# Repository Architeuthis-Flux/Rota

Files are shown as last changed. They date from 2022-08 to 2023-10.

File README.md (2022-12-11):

# Rǒta
Here are some different Rǒtas with different options


IMG_0975b copttty



1_0_GIF_2 4

That flashing means it wants your input. These decimal points do way more work than regular decimal points, they tell you a lot about what's going on. When you don't have segments to make crude letters and stuff, you need to get creative with dots.

https://user-images.githubusercontent.com/20519442/197625332-2014cbfb-5107-4166-b01f-a8d20bc4a214.mp4



Rǒta is a tool for counting things while being all nerdily extra about it. Are there more efficient ways to count things? Yes. But will those things increase your exposure to Nixie tubes and rotary dials? No? Well then if that's what passes for progress nowadays then I'm going to go live on a mountain somewhere and count things the cooler way, with nixie tubes.

IMG_0975b

It was originally conceived as a gift for a duck hunting lodge, but now I'm making a few more and I know not everyone is into hunting so it's been generalized into a tool for just counting stuff in general where those $3 hand clickers or a golf pencil just lacks the glamour you need in your life. 

Instead of using sequences of numbers to use the special functions, now you just dial 0 and then the function you want which is printed on the number plate. 

here's the special function menu map
```
note - I'm calling moving the dial just a little to turn the display on a "click"
when inside a special function, dial anything to exit (preferably 0 because it's only reading intermittently when in menus, so it's most likely to register)

0 -- enter/exit menu or function   shows 111 when you're in the menu)
1 -- stopwatch                    click to start, click again to see last time.
2 -- show battery voltage         briefly turns off the display to get a more accurate reading (not under load)
3 -- new day                      this stores the total since the last time you started a new day. maximum 63 days
4 -- does nothing
5 -- enter a count by digits      enter 3 digits (hundreds - tens - ones) to add to your daily total
6 -- show history                 click through each day with first the day number (on the left) then the total for that day
7 -- toggle day/total display     either shows the count for that day or the running total of all days (default is total)
8 -- golf mode                    keep score for golf - first enter 1-4 players and the decimal points show which player's turn it is
9 -- clear everything             dial 9 again to confirm. dial anything else to go back
999999 -- emergency clear         dial 9 six times to emergency clear everything in case something gets messed up same as dialing 10 9 9
                                  you can also short the middle pulse pin high for super duper emergency clear

```

The voltage display was added because I was having issues with the K155ID1s browning out before the HV module (it still blows my mind that it works down to like 3V), so the display would just show all the digits on because the nixie drivers weren't blocking any current. 

So now I added a HV shutdown and a super simple voltage sense divider that drops the 9 down by half so it can be read by the AVR64DD32's ADC.

Now if the battery voltage is too low, it shuts down the display but still takes input. In case you don't have a spare battery but still want to count. And the power draw is so low for just the microcontroller that the battery life might as well be infinite.

https://user-images.githubusercontent.com/20519442/197626419-59003e0c-a97b-495f-a466-c8ea541df162.mp4

If you notice in the video, the display flashes when the battery voltage updates, that's because when it does the measurement, it briefly shuts the HV module down so we can measure the battery voltage unloaded. Because this thing draws ~300-400mA when it's on so without doing a ton of math and testing different 9v batteries to correct for it, the voltage it shows would be like ~2V lower than it really is unloaded. 

I probably should have put in a fresher battery before I filmed this. 

I also had to design a case for this because I'd always get anxious watching other people use it without one. People with smaller hands tend to put their fingers right on the high voltage section on the back of the Nixies. 


This project really helped me change my lukewarm feelings towards rapid prototyping, I've had a 3D printer for years but never really used it much. I found out the reason it never worked is the original spool of filament Sindoh included was garbage. So my prints would always turn into an absolute mess of spaghetti. I finally bought a fresh spool of filament and it works great now.



I'll definitely have the case made by someone with a more expensive printer when I sell these or give them away, but to get the fit right and make sure there's room for everything inside, 3D printing really saved the day here.

RotaNumberPlate

Putting in the number plate (which I just found out the name of) on these old dials really makes you appreciate how much thought they put into things in the 60's. Like on most phones you would only do this once, but they came up with a really cool system for it.

How you do it is by sticking a screwdriver under the ring at the 6 and moving a lever down to the 8 position to release the middle thing.




With it off you can see what's going on 



Then you just twist this pressure plate and it comes off. 



This isn't the final number plate from above because I'm a millennial and don't have a regular 2D printer. But I might try it on a plotter or a silkscreen to get a nicer finish.

I had to move the holes a bit to get it to line up with the dial, I must have carelessly moved the holes on the Edge Cuts layer in Kicad, but the new Kicad files on here are fixed (as well as a couple other problems) if you want to have these boards made yourself. 



Yes I cleaned that flux off. For Nixies it's particularly important because flux lets enough current flow at that voltage to cause ghosting. I had a lot of problems wit ghosting on the first digit and I tried a bunch of things to get rid of it, eventually what fixed it for me was putting a 220KΩ resistor between high voltage and ground to both drop the voltage a bit (these tiny HV modules don't have an adjustment knob like the bigger ones) and bleed off the extra charge you get when you do low-side switching on nixies.



PCBway was nice enough to sponsor this project. I had never used them before but the boards they sent were great. And their matte black finish is really velvety. 

It really seems like they spend a good deal of time with a human looking at your boards and making sure there aren't any problems. And I usually do a lot of weird stuff with my boards that falls outside of the usual best practices of PCB design. But they seemed to roll with it pretty well and make sure I did it on purpose (that came up a lot more with breadWare which they also sponsored.) Which is crazy to me because of how cheap the service is. You'd think it wouldn't be worth their time for my ~$20. 

Either way, I was ready to just pay them for my boards if they were shitty and say so here. But that wasn't necessary because they really did a great job on these. 

# RotaDuck (this is the previous revision so I'm leaving this here)
Sticking Nixie tubes to an old rotary telephone dial

Here's a video of it in action

https://user-images.githubusercontent.com/20519442/176002505-34b7ac66-cf38-471d-8984-42ffa85f04d7.mp4

And there's a few more on my [Youtube channel](https://www.youtube.com/user/arabidsquid/videos)



I'll do a more complete write-up at some point in the future, but for now I'll mention a few things.

It stores the running count (and a history of recent entries) in EEPROM because when the dial returns to it's resting position, the power is completely cut off. That makes it so I couldn't just use timing to figure out when the pulses stop (and the number that was ultimately dialed) so instead I put in a resistor ladder so the between the 3 contacts on the dial to give me 1/2 voltage on the last number, when the dial is between 0 and the end. that gives me a waveform like this:
```
   _   _   _   _
__| |_| |_| |_| |_,-,___
```
So it does all the saving during that shorter last pulse, which is pretty tight because EEPROM access is relatively slow. 



I didn't want to add any buttons to it so instead it uses multiple 9s and 0s for special codes, here's the list of what they do
```
0   - subtract the next number dialed from the total
000 - clear all counts to 0

9   - show total for all days
99  - list each day and the total for each
999 - start a new day
```
Here's what I'm talking about when I say days. So this was originally designed for duck hunting (hence the duck in the name) as a gift for a duck hunting club. If you want to count how many ducks you got, we'd usually bring one of those mechanical clicker counters and just keep a running total.But I figured if I'm making a thing to count how many ducks were shot during a trip, it might also be useful to have that information separated by days if you want to keep a separate daily and running total. 

At some point I'll print that menu in the middle of the dial.



If you intend to make one of these for yourself, you should probably know this thing is like 90% bodges and perfboard circuits. I eyeballed the shape of the dial cutout nearly perfect, except that it's flipped on the board. So instead of just redoing the board like a sane person, I just mounted it with everything on the wrong side and bodged wired a ton of things to make it work. That's why there are those arrays in the code to convert the number shown to the number its actually wired to. So if you really want one, let me know and I can do a version 2 that will be 100x easier to put together. 




I also made a rechargeable one by dead bug soldering a tiny 10DFN MCP73213T charge controller and putting in 2 1/2 AA sized lithium batteries, but after using it a while, the simplicity of just using a 9 volt battery is much nicer (and lasts a lot longer.)


Eventually that red wire sticking out will be connected to a barrel jack port. Once I decide on an enclosure.


oshw_facts (1)

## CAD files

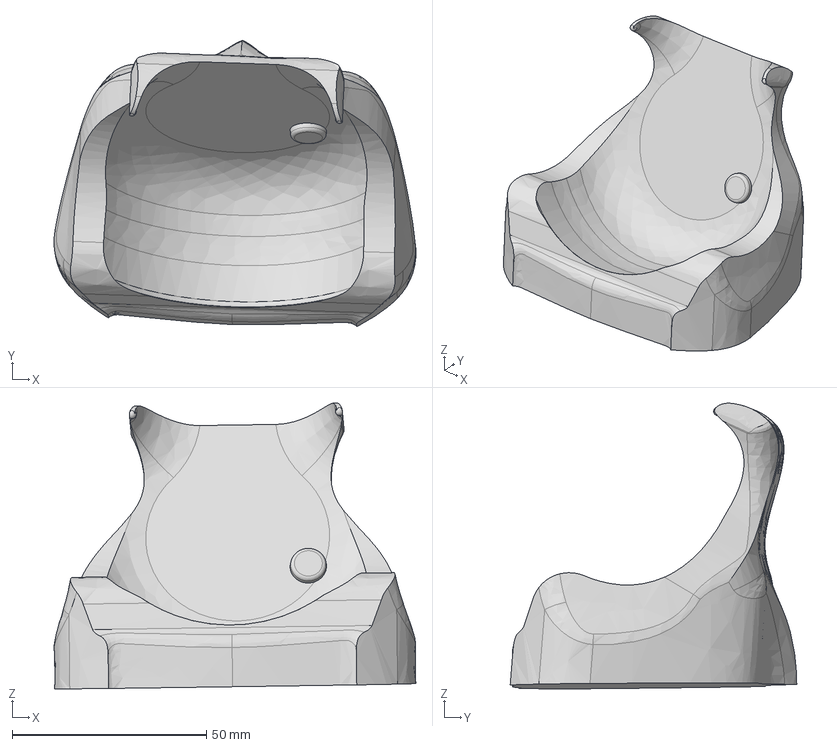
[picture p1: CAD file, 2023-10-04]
Case 3D Models/stand2lean v2.step
93.3 x 73.8 x 73.6 mm

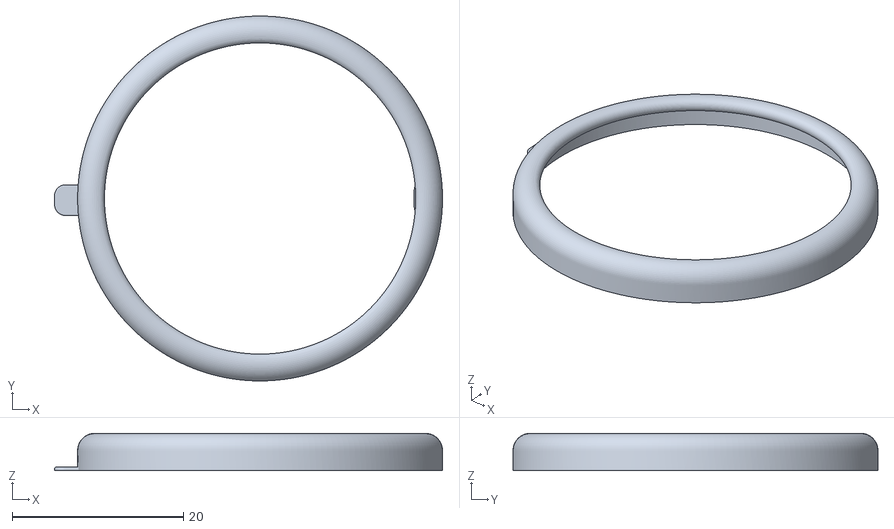
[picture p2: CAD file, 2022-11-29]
Case 3D Models/centerset4 copy.stl
45.3 x 42.6 x 4.36

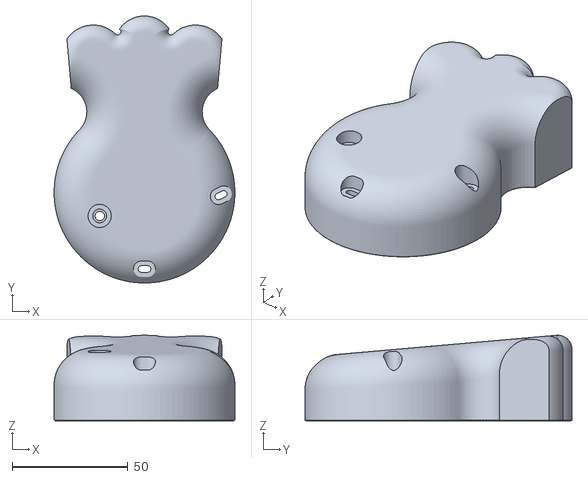
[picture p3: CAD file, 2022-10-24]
Case 3D Models/Bodyds9.stl
78.0 x 115.1 x 36.9

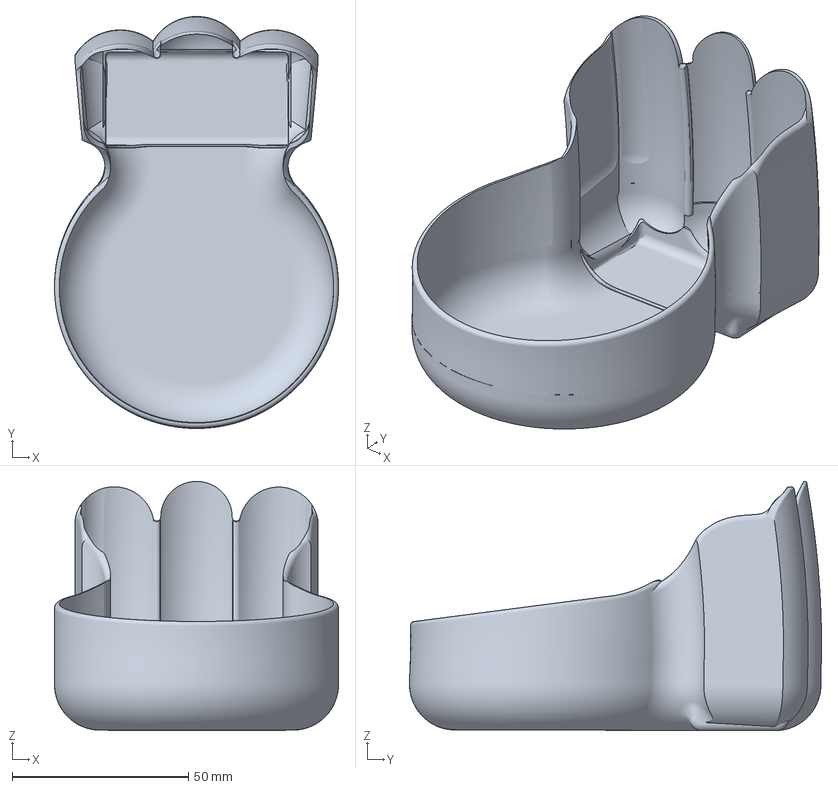
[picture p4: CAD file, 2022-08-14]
Case 3D Models/Rota7.3mf
80.5 x 116.8 x 70.6 mm

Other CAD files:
Case 3D Models/stand2lean v2.stl

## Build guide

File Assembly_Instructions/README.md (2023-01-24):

# Rǒta Assembly Instructions

Congrats on your new Rota! Now let's put this thing together.

## Here's what you should have in your kit
Assuming you got the full kit, you should have:

* 1 Rota PCB with assembled SMD parts
    * (If I gave you one with a warning about there being some issues that need to be fixed, [here's the guide to fix them](RotaErrata.jpg))
* 3 [IN-12B](http://www.tube-tester.com/sites/nixie/dat_arch/IN-12A_IN-12B_03.pdf) Nixie Tubes
* 3 [K155ID1](https://tubehobby.com/datasheets/k155id1.pdf) Nixie BCD drive ICs
* 1 [IN-3](https://tubehobby.com/datasheets/in3.pdf) Neon indicator bulb
* 1 [NCH82000HV](https://omnixie.com/products/nch8200hv-nixie-hv-power-module) High Voltage DC-DC converter module
* A Bag containing:
    * 2 printed number plate cards
        * If you ordered a plastic dial, I've also thrown in a slightly smaller number plate card that might look better with them, but you can use either one.
    * 2 plastic number plate covers
    * Some extra plastic spacers for the dial contactors
* Another bag containing:
    * 7 ~2" bits of wire
    * 6 Terminal lugs
    * 2 1x3 Male header pins
    * Some short bits of heat shrink tubing
    * 1 9V battery connector
* 1 Dial insulator
* 1 3D printed case

## Here's what you'll need that isn't included

* Soldering iron
* Solder
* Small-ish flathead screwdriver
* Flush Cut wire cutters
* Small needle-nose pliers
* Something to remove flux (isopropyl alcohol or flux remover or whatever)
* A multimeter (optional, sort of)
* An Xacto blade
* You might need some 1" screws that thread into your dial to attach the case
    * The threads these dials come with have an old thread pitch that's hard to find machine screws for, if you ordered the dial from me, I've recut the threads to fit 4-40 machine screws. They're close enough in pitch and the metal these dials are cast from is soft enough that if you really want to, you could probably just force a 4-40 screw in there and cut new threads that way. 

## Step 0 (checking my work)
The AVR64DD28 microcontrollers were soldered on by hand without the use of a solder paste stencil (the rest of the parts are already populated by JLCPCB so it wouldn't lay flat enough to be helpful), I check each one for shorts an unconnected pins but it's always possible that I missed something. So it might be helpful if you're the meticulous type to put your multimeter in continuity mode and make sure adjacent pins arent shorted. If you find one, I usually just use an Xacto knife blade side up and sort of floss between the pins to cut any tiny solder bridges. 

Or you can trust my work until the end and only do this if there's a problem. 

# Step 1 - Nixie Driver ICs

First, stick in the ICs so the notch aligns with the one silkscreened on the board. 
You'll probably need to bend the pins in a bit to get them to line up with the slightly smaller than usual through holes. 
ics 

A thing to remember here is that this board will be laid flat against the dial, so it's important to keep everything on the back side super flush with the board.
I find that pushing them in really snug into the holes, cutting all the pins flush, then letting them come back out a fraction on a millimeter before soldering gives really flat solder joints. 
ics 
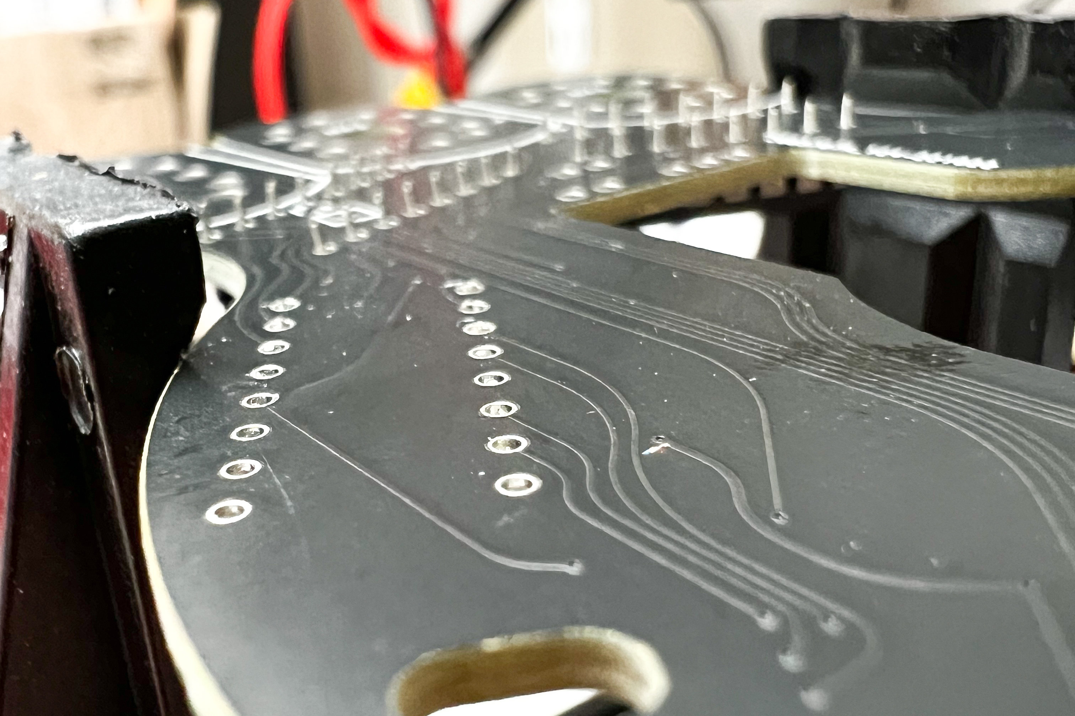
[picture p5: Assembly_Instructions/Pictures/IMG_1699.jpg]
 
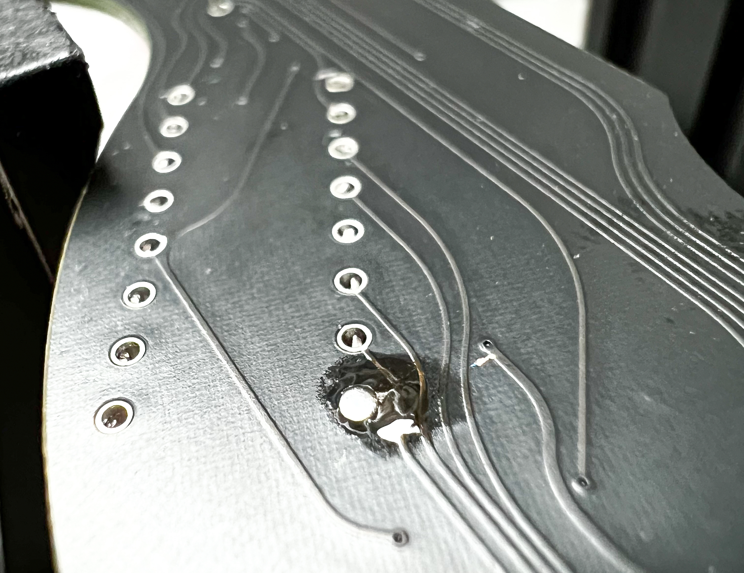
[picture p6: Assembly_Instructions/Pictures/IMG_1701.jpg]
 

# Step 2 - Dial Lugs / Battery Holder
Now we need to make the dial lugs that will connect the board to the dial. 

First, grab one of the lugs with your pliers on only one side of the split
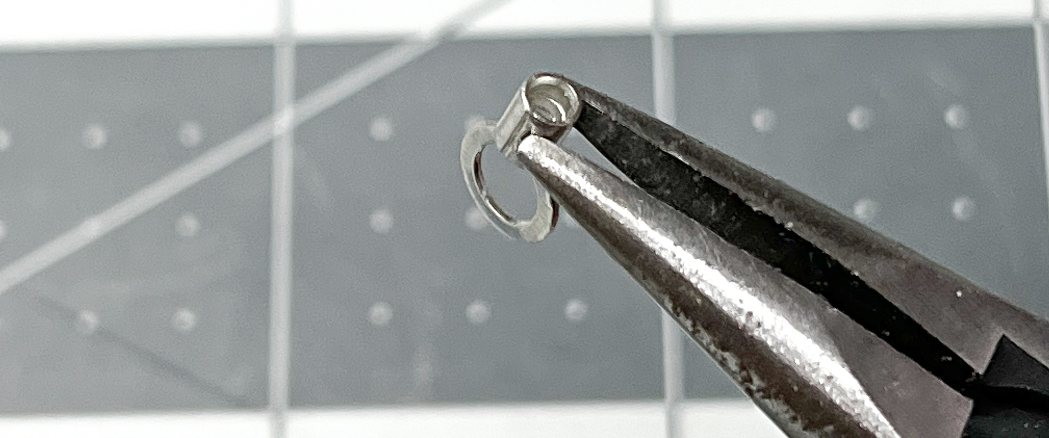
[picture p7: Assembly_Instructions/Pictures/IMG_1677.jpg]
 
and squish it most of the way down (leave enough room for the wire.)
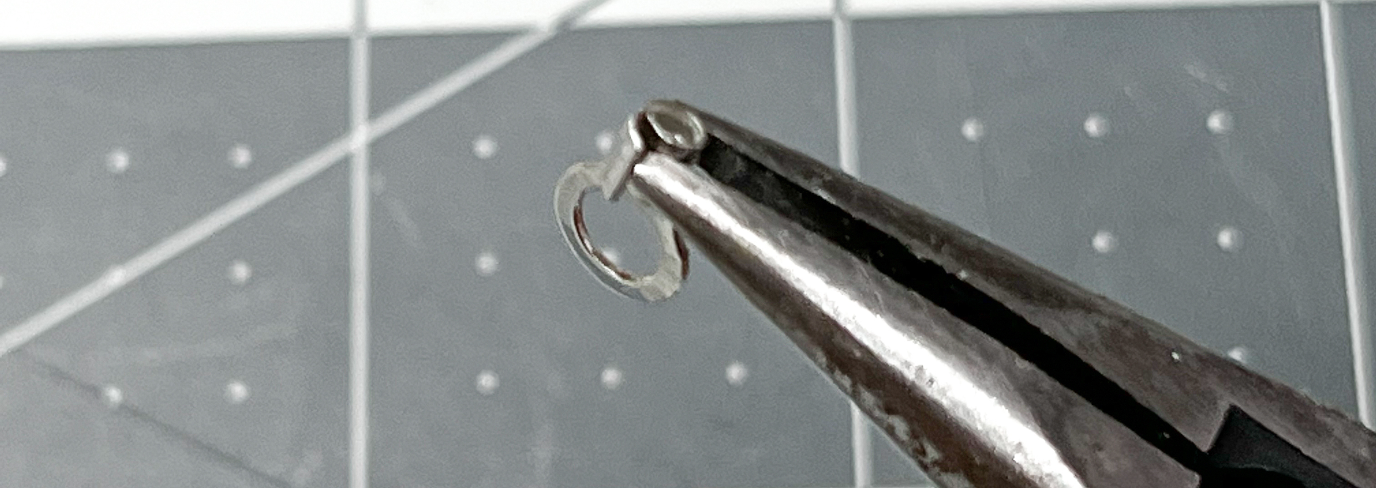
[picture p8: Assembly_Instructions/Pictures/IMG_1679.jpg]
 
Now strip off like 1/4" of one end of a wire and stick it in
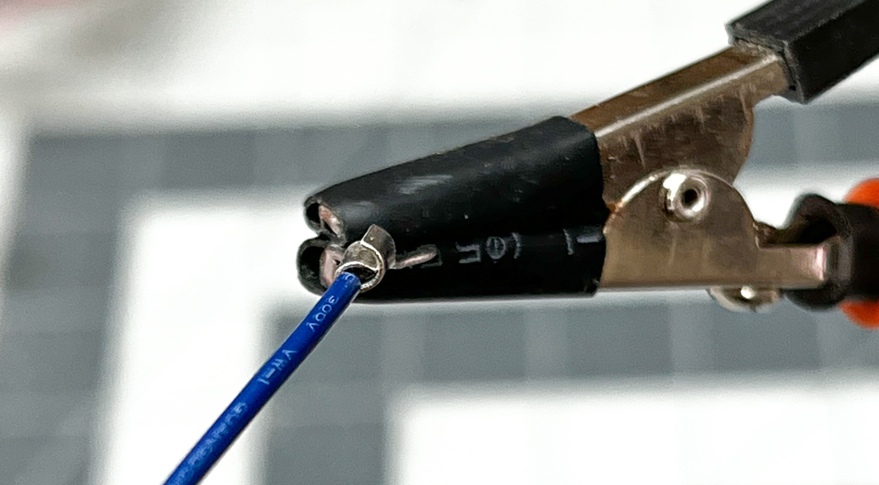
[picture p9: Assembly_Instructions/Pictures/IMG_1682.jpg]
 
Squish down the other flap so it holds the wire snugly, you might want to press the sides in a bit so it's not so wide and flat.
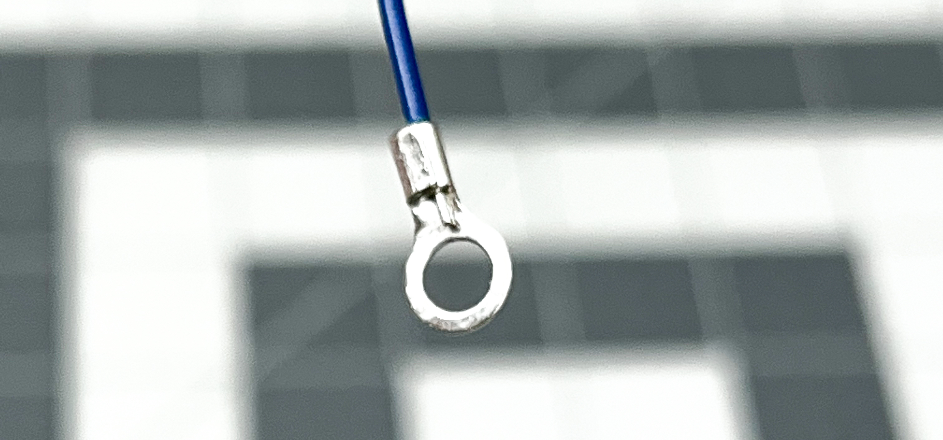
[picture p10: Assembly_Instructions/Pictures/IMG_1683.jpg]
 
Add some solder
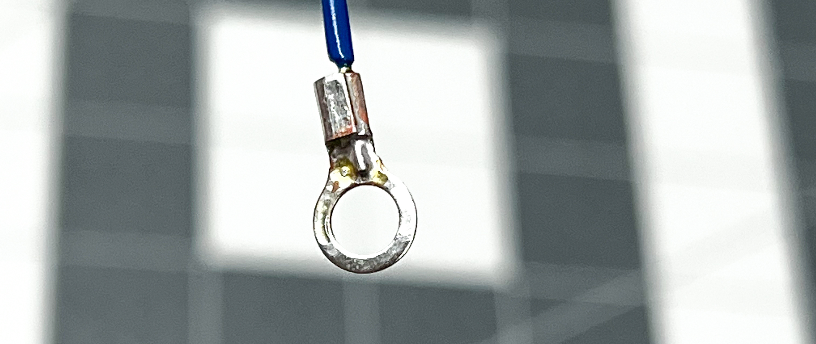
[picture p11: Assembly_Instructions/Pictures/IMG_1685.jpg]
 
and heat shrink it
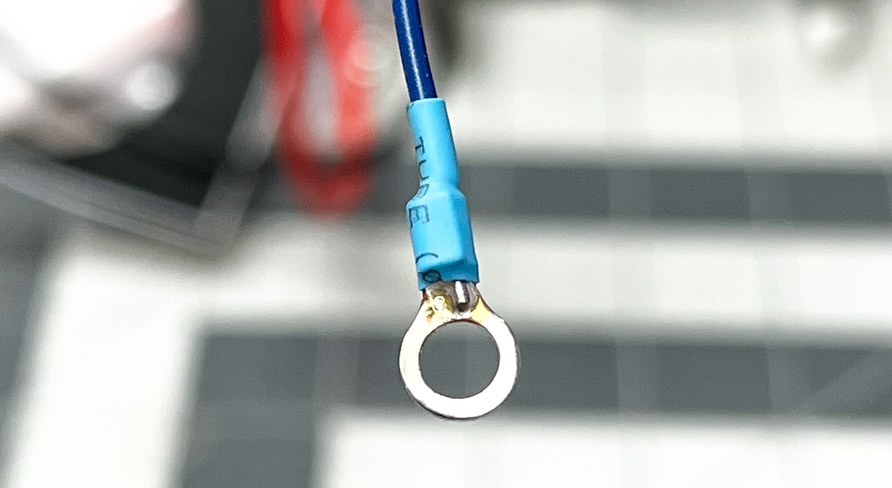
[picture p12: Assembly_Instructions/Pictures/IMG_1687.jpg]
 

Now repeat this process 4 more times until you have 5 soldered up lugs/wires. (Most kits have the forked style seen at the far left here, these were just extras I had laying around)

lugs 

Cut and strip them so theyre about 1 1/4" long, and stick them in the 5 holes.

To get them to stay while you solder them, I bend them back and tape them down like this
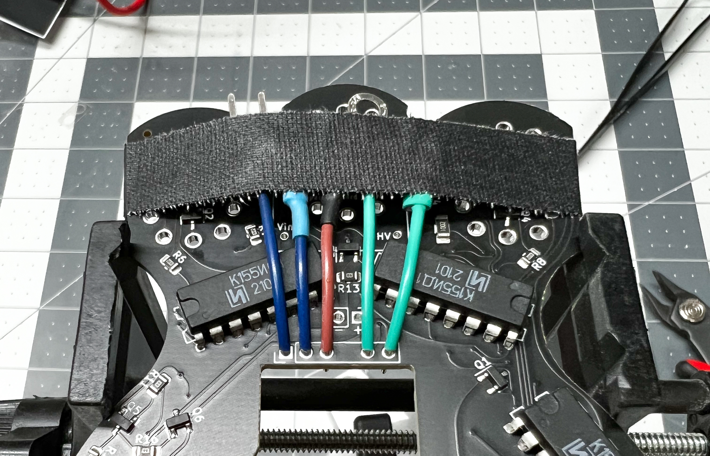
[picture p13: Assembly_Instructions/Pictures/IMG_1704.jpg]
 

We still want to keep the back of the board super flush so cut the parts sticking out and then solder them. 

With the battery holder, cut and strip the wires down to about 2 1/2" and solder them in (Red to + , black to -, obviously)

If your board has 6 holes (There's only 1-2 floating around in the wild,) just dont put anything in the 4th hole from the left.

# Step 3 - Nixie Tubes
This part I find is worth being a little picky about looks, you have 3 nixie tube that are matched for overall look as best I can, but once you start paying close attention to each one, you notice that there's a lot of variation from tube to tube. So it's a good idea to put shuffle the order of the tubes until you find an order that looks the most even to you. 

Most of them are a bit off-center in some direction, so part of the matching I do is to make sure if there's one that sort of goes to the left, there will be another that goes to the right. 

Once you have the order down, I set the whole thing face down with something supporting the bottom of the board so it all is flat

nix 
And then just solder the top pin of each tube. 
nix 

Now you can flip it over and melt the solder while adjusting the positions of the tubes so they're all evenly spaced and at the right angle and stuff. It's worth spending some time here getting it right because they're a huge pain to desolder once they're in.
nix 
(These are some *very* unmatched tubes, interestingly, the two on the left have the same date code)

Pro tip: use the outlines on the front of the board as a reference

Once you get it perfect, solder and cut all the pins (don't use your good cutters, these pins are hard and will ruin them)
nix 
Getting them super flat isn't important here.

Now make sure to clean the flux off *super duper extra* well here, like more than you'd usually deem necessary. At high voltages flux isn't a perfect insulator and the tiny current it passes is enough to cause other digits to partially come on that shouldn't be and it looks terrible. Like 90% of the troubleshooting I've done on these things ends up being flux related.

# Step 4 - HV Module
You'll notice that there's only 3 holes where the HV module connects to the board. That's because the two ground pins are connected and I needed to save space here. 

The board mounts with the parts facing toward the nixies to get some extra clearance for the 9V battery in the case. 

Find a 1x3 header and break it into individual pins (if you break the plastic part don't worry about it)

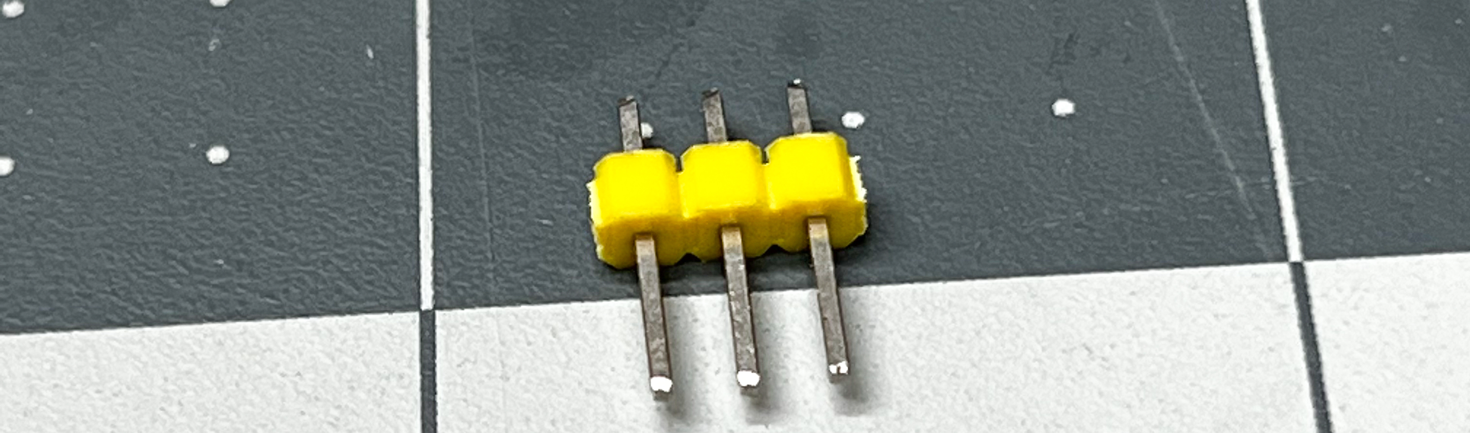
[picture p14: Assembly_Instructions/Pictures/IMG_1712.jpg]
 
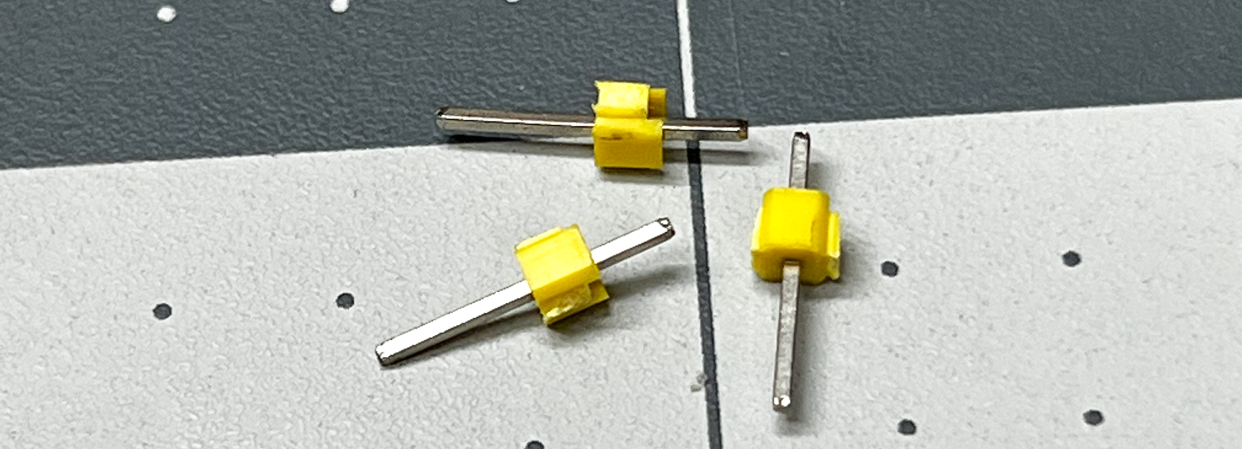
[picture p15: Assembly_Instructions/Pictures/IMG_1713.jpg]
 

The through holes on the Rota board are tight enough that they friction fit pretty well. Put the pins into the Rota board and then put the module on. 

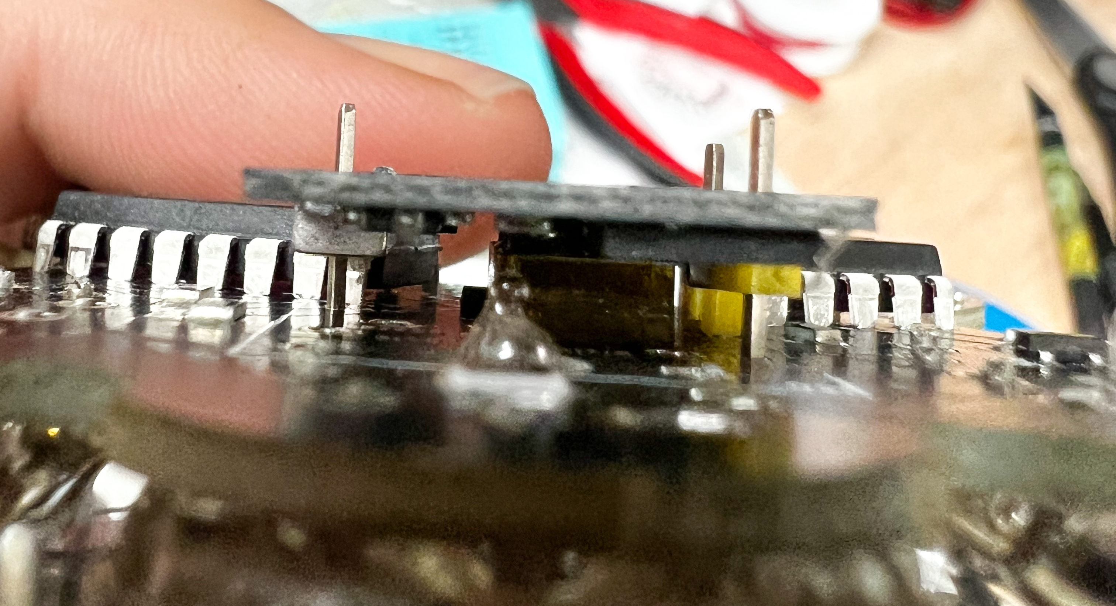
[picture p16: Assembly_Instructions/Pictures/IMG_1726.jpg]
 

You want to press the board down enough that the big square inductor on the board is as close as possible but not touching the Rota board. And that the evacuation nipple on the nixie tube isn't touching either. 

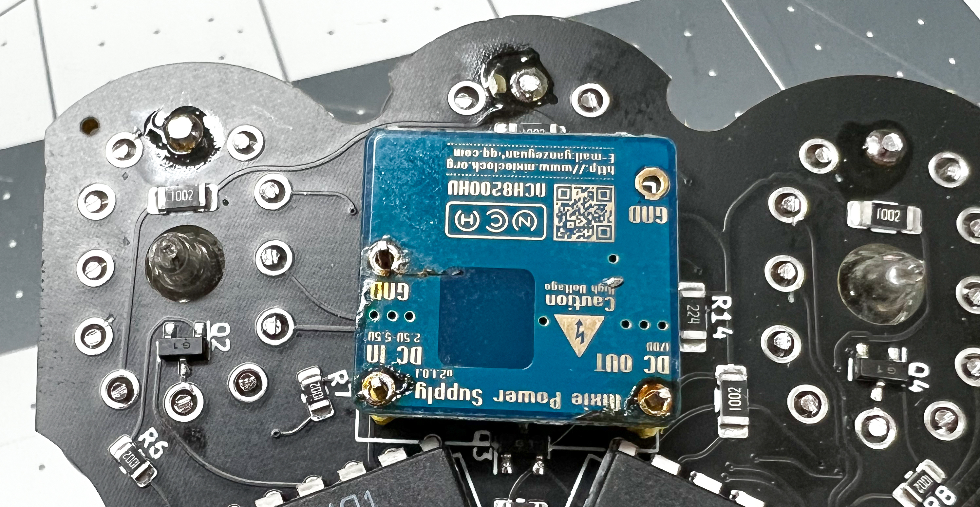
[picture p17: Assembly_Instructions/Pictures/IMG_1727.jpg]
 

Cut those pins super flush and then only solder the pins to the HV module. It stays in with friction so I usually wait until I know the board is working to solder it onto the Rota board.

# Step 5 - IN-3 Indicator
Use one of the small heat shrink tubes to measure out a height you want your IN-3 to sit at. 
in 
I usually prefer it 1/4" below the face of the nixie tubes. But it's up to you.
Now cut it and the other to that length and put them around the leads of the bulb and shrink it. 

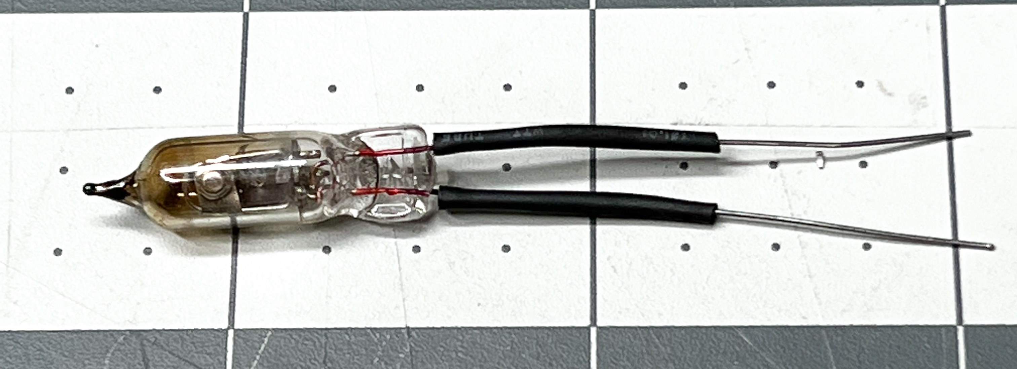
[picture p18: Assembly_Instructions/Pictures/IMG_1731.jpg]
 

Note that there are 2 sides to these bulbs, this is the side you want facing out
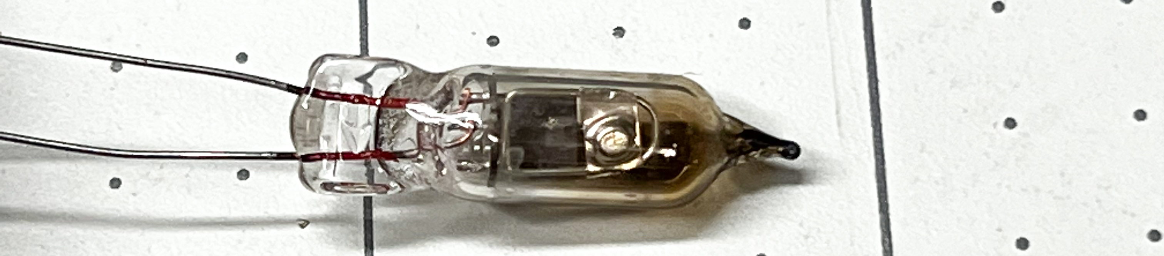
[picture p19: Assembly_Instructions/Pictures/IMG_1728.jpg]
 
This is the back side you want facing in towards the board.
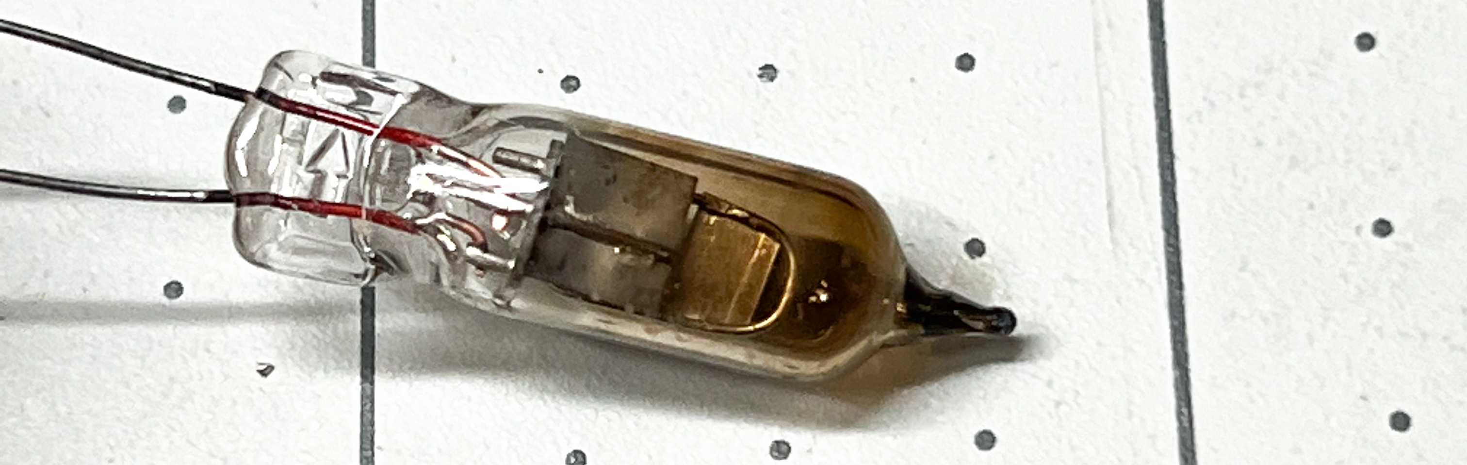
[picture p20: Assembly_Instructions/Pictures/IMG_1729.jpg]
 

(You can power these backwards and the glow comes off the wrong parts and looks kinda weird, feel free to try it if you want, it won't damage the bulb.)

Now cross the leads (because the footprint on the board is backwards) and cut the leads to a little over 1/8" 
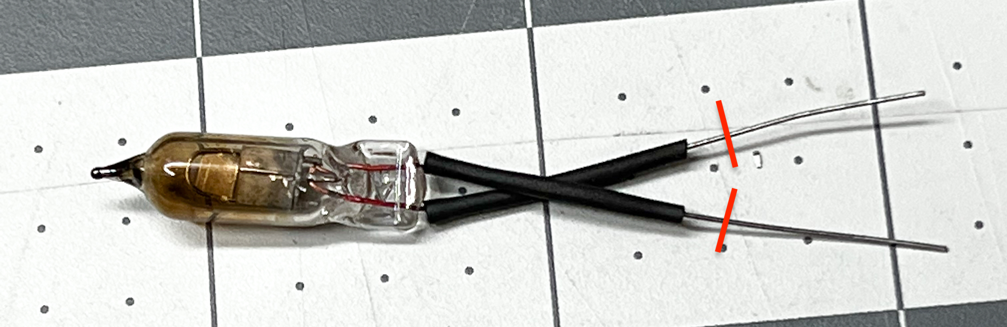
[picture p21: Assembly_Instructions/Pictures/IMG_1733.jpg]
 

Stick it in the board and solder it from the front. 

in 
in 

# Step 6 - The Dial

If you got a dial from me, this part should be done already. This is by far the trickiest part of this process. What we need to do is take a dial that originally comes like this 
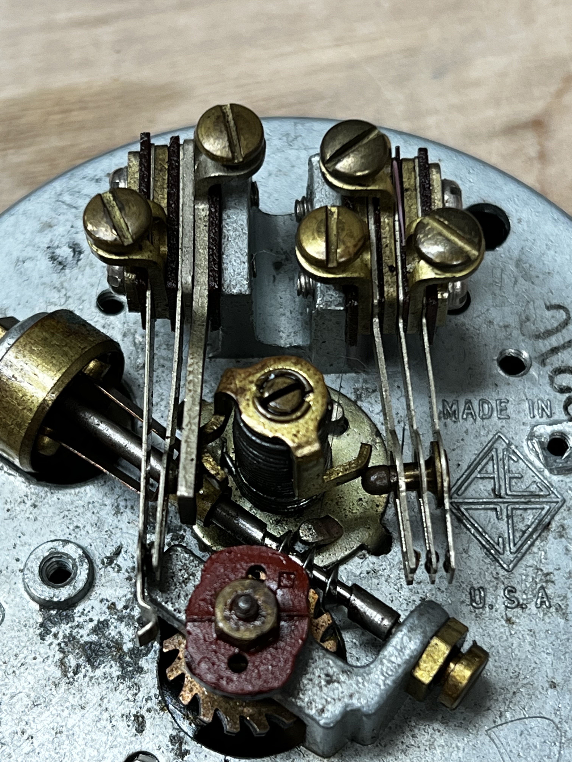
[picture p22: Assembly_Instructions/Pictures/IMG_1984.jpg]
 
And move one of those screw teminals from the right to the left side so it looks like this
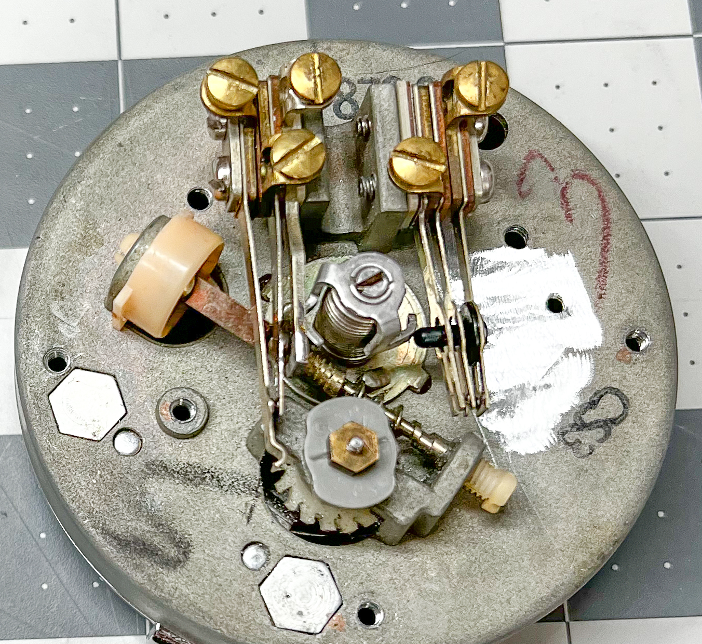
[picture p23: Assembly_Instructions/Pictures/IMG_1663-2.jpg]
 

## The Flattening
Depending on the dial you have, some will have a raised screw hole on the left side near where it says "Made In U.S.A." That needs to be sanded flat (shown in the picture above) or just use cutters and clip it off. It's cast zinc so it's surprisingly soft. 

Now the only thing sticking up should be the one on the left. 

## The Insulating

So the dial doesnt short any contacts when it's screwed tight againt the board, there's a piece of cut out gaffer's tape in the kit

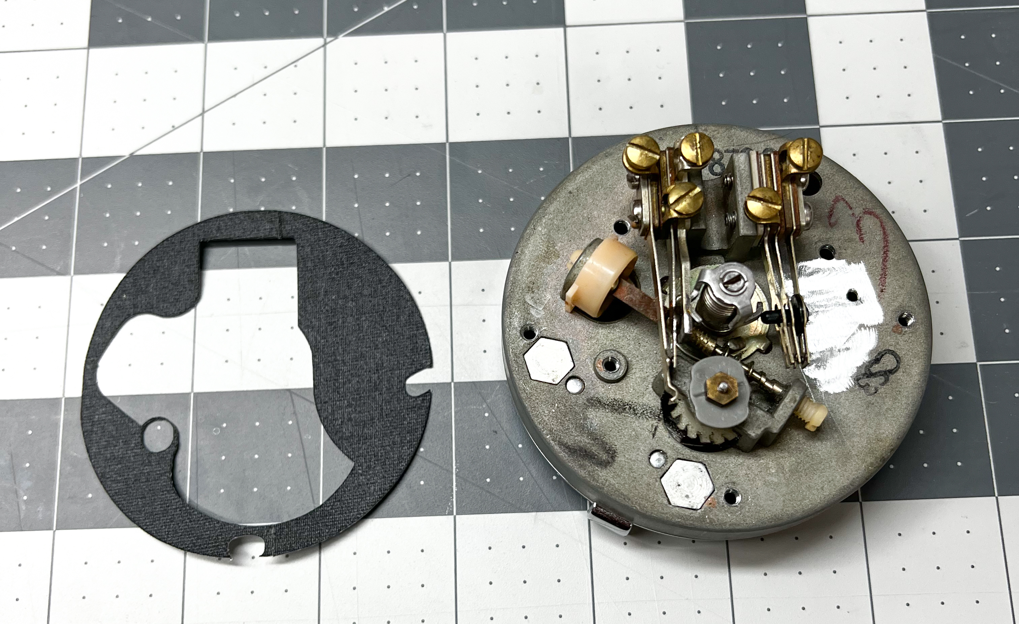
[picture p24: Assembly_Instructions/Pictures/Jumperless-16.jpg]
 

Use tweezers to peel each half off the backing and do your best to stick it on lined up with the holes (perfect alignment is not crucial)

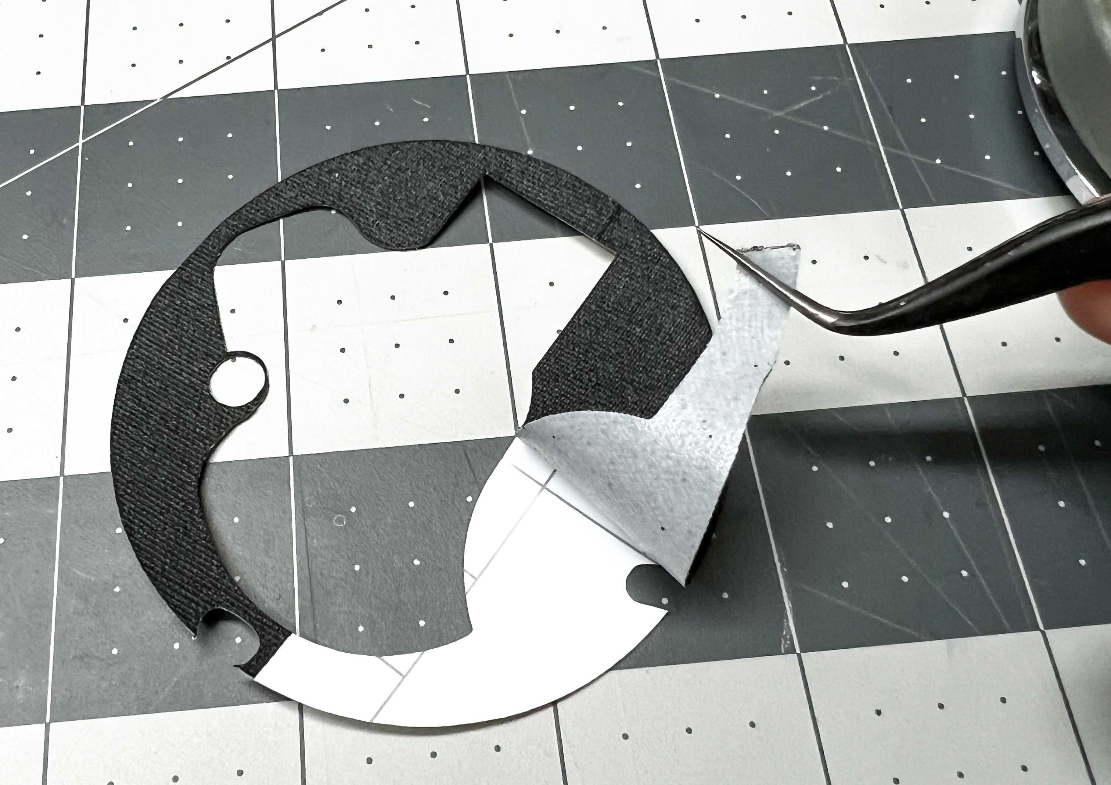
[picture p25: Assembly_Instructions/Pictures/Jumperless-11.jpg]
 
dial 
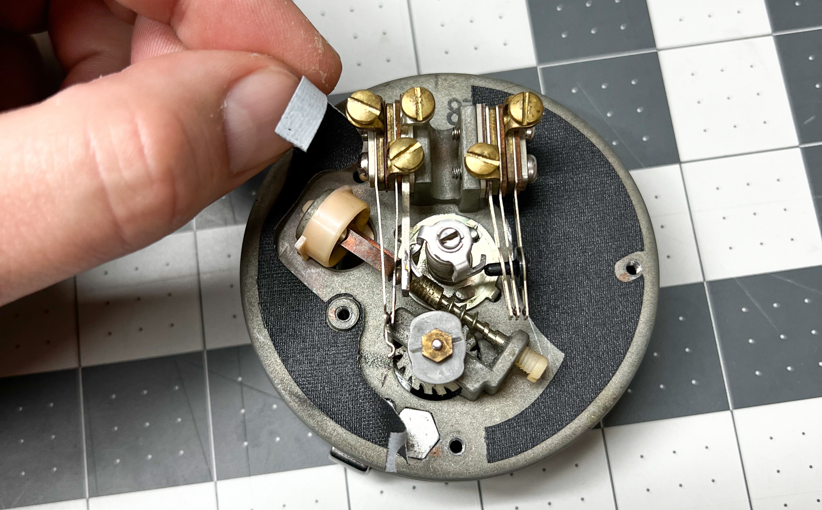
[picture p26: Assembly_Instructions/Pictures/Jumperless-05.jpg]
 
dial 

## The Fiddly Bit
I can't step-by step through this part because it's a bit different for each dial depending on age and wear and stuff. but here's the final goal

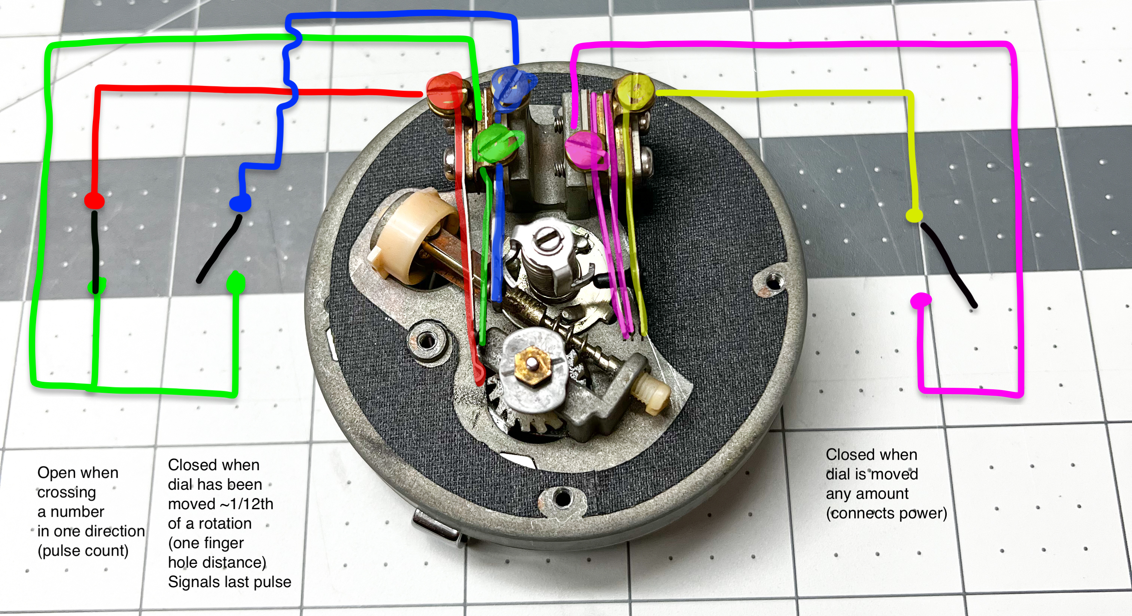
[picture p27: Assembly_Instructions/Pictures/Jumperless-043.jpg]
 

Here's what that looks like on an oscillocsope

The traces go from left to right, 

trace 1 is the pulse (left side, left contact, red above)

trace 2 is pulled to ground through a 10K resistor (left side, middle contact, green above), 

trace 3 is pulled high through a 100ohm resistor (left side, right contact, blue above)

trace 4 is continuity through the right side contacts

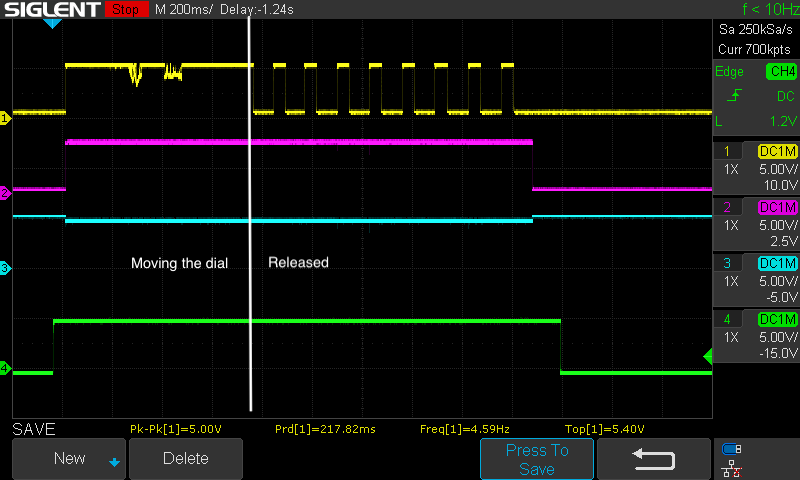
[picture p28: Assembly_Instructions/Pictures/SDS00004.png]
 

So unscrew the the screws holding the contactor arms

dial 

and lay them out in order 

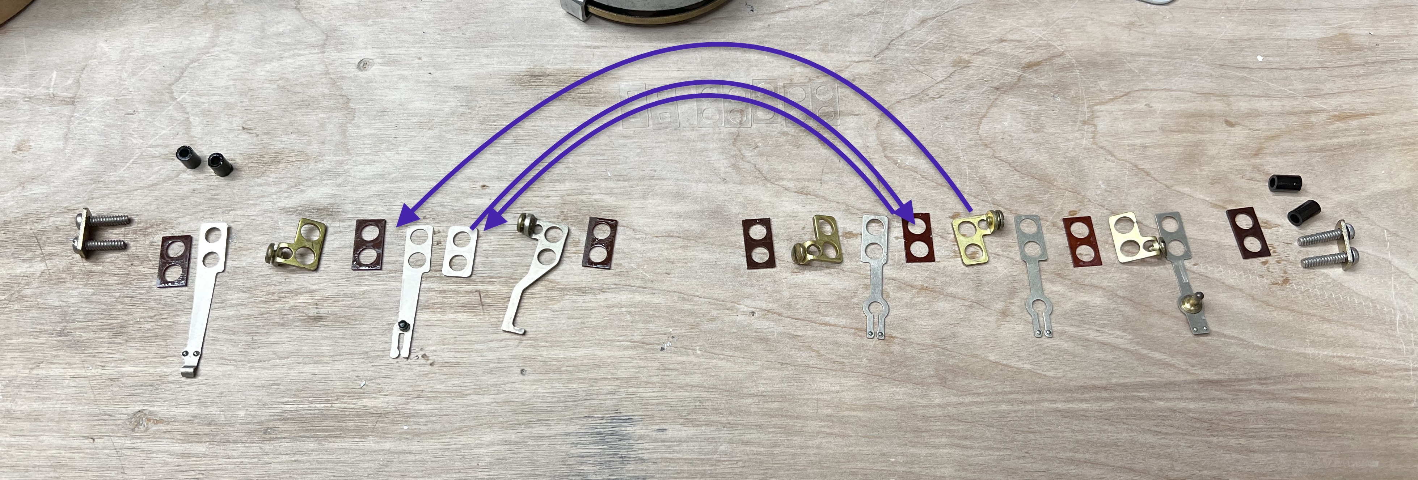
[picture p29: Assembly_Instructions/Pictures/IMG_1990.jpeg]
 

swap the parts marked with purple arrows and flip the metal pice with the screw terminal around so it faces away from the one next to it when you put them back on.

Make sure each of the contactors on the left side are isolated from one another.

Its helpful to cut those plastic spacers around the screws like a millimeter shorter and fillet the edges so they dont catch on the edges as easily.

Now put all the parts back on the screw and screw it all back on. Watch carefully to see if the contactors are making good contact when they should. 

They probably won't, you're going to need to add and remove spacers (and replace them with the thinner plastic ones I've provided) by trial and error until good contact gets made at the right times. You can bend the arms slightly as needed. Make sure everything's screwed in tight when you test them. 

This is an absolute pain in the ass. But don't give up, once it's set you wont have to do this again. 

Here are some examples of working stackups for reference (one has 2 extra arms on the right side but they're unused)

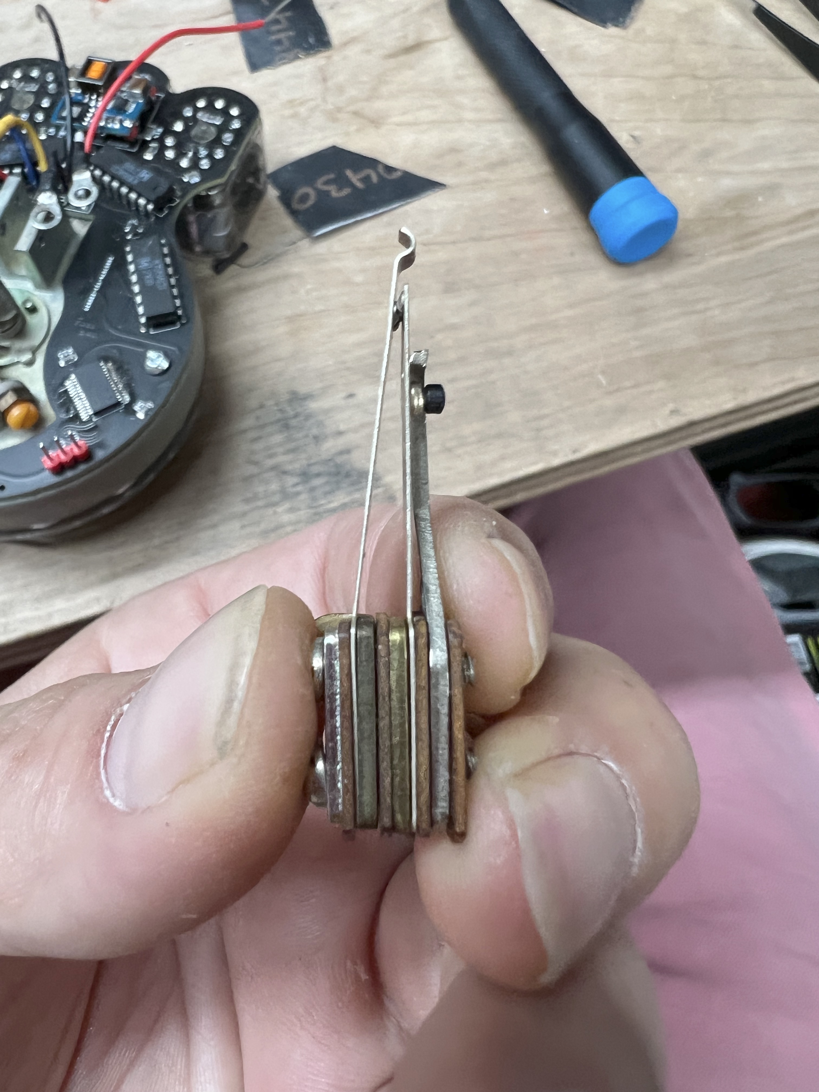
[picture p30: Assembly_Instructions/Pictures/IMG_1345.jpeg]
 
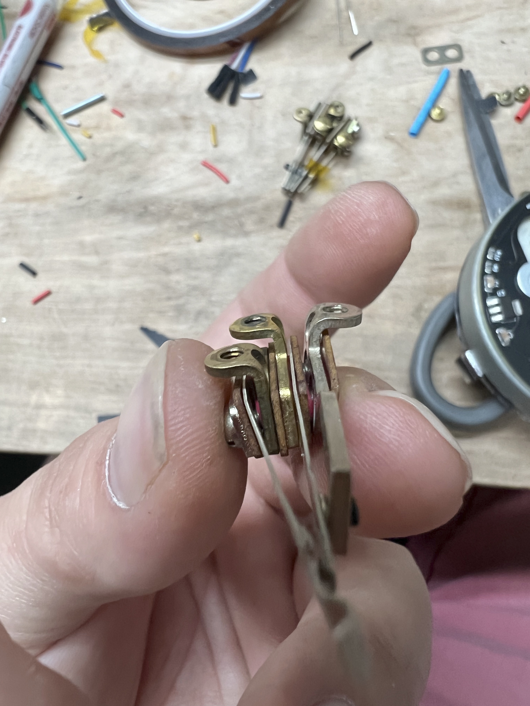
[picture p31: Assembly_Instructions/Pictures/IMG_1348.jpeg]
 
dial

At rest
dial 

Moving the dial
dial 

Mid pulse
dial 

You may have to sand some oxidation off the rigid arm on the left side where it meets the middle arm, maybe add a bit of solder. It was wasn't meant to make electrical contact with that arm so sometimes it needs a bit of help.

Here's some Slow-mo video of what it should look like

https://user-images.githubusercontent.com/20519442/201819503-7cee38f8-5ffb-4e9a-b226-030ce2a6f39d.mp4

If everything was done correctly you should be able to screw the lugs on the board into the terminals on the dial and it should work. This is also a good way to make sure your contactors are set up correctly, if they aren't the nixies will just show 0 and won't count when you dial. 

Now just put in a 9V battery, screw on the case and enjoy your rotary dialing adventures.

## So thats it! Your Rota should be working now!

Sometimes the microcontroller will get in a weird state during assembly, so if it's showing anything but 0 when you first turn it on, try doing a hardware reset by connecting the center contactor on the left side (looking at the back) to 5V (you can alligator clip it to the pad labeled 5V at the bottom of the board) at startup like this: 
Reset
That should get it completely reset and ready to count.

If you have any issues with assembly, feel free to email me at [KevinC@ppucc.io]( KevinC@ppucc.io) and I'd be happy to help with any problems you may run into.

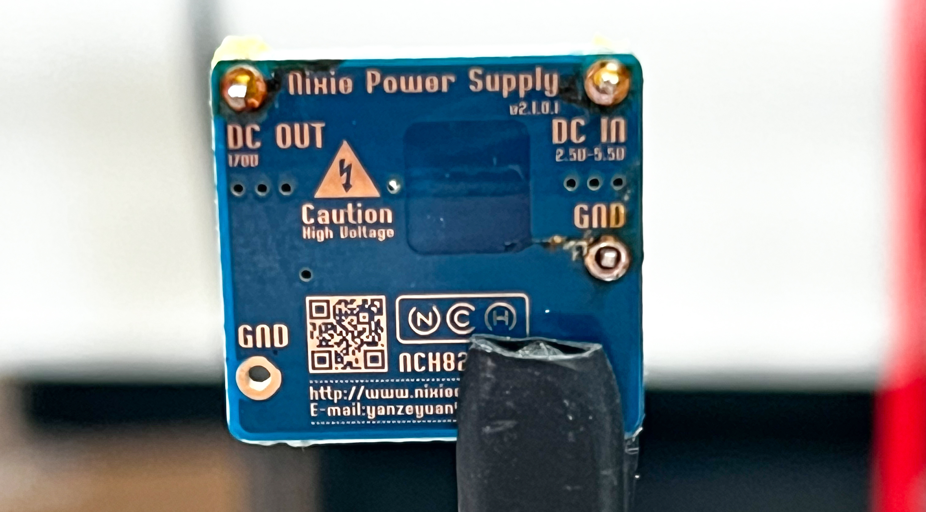
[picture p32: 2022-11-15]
Assembly_Instructions/Pictures/IMG_1716.jpg

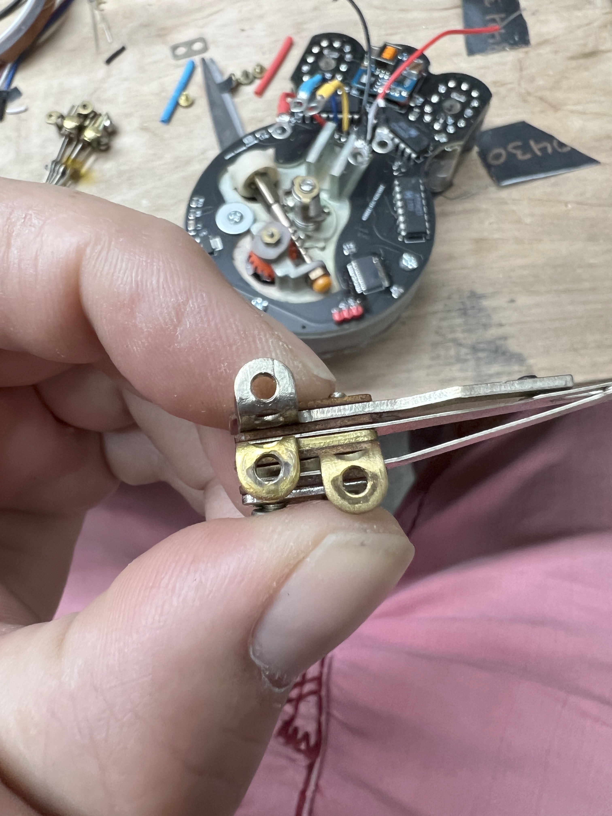
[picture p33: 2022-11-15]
Assembly_Instructions/Pictures/IMG_1346.jpeg

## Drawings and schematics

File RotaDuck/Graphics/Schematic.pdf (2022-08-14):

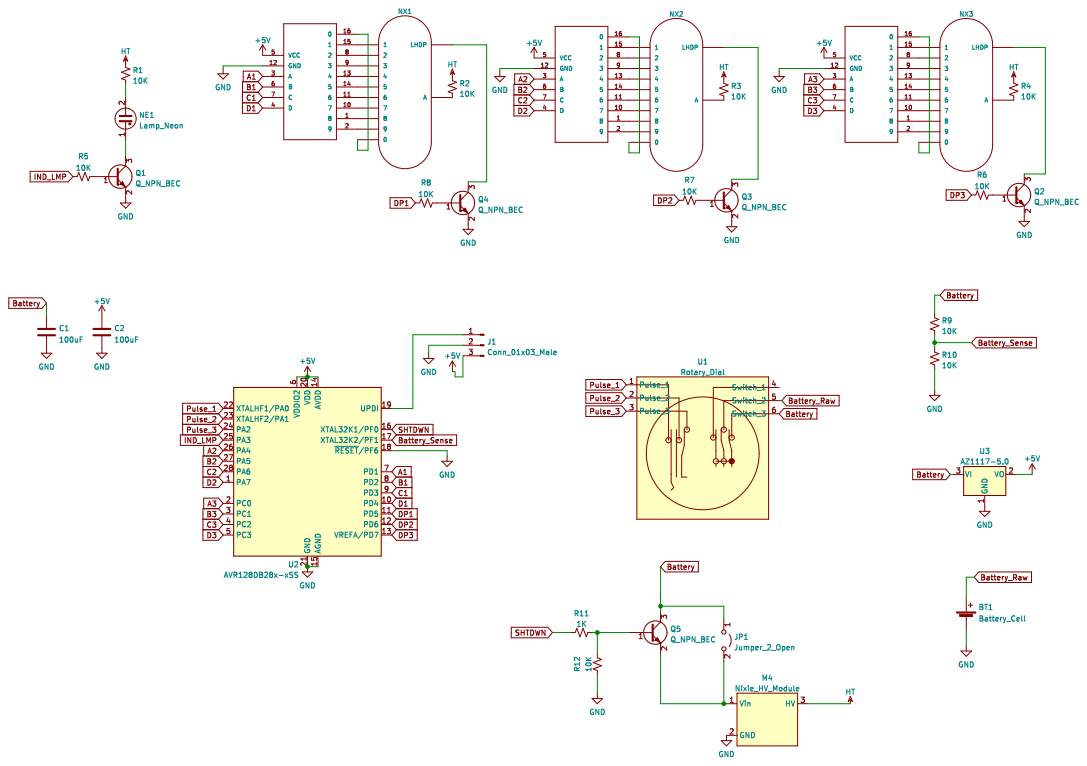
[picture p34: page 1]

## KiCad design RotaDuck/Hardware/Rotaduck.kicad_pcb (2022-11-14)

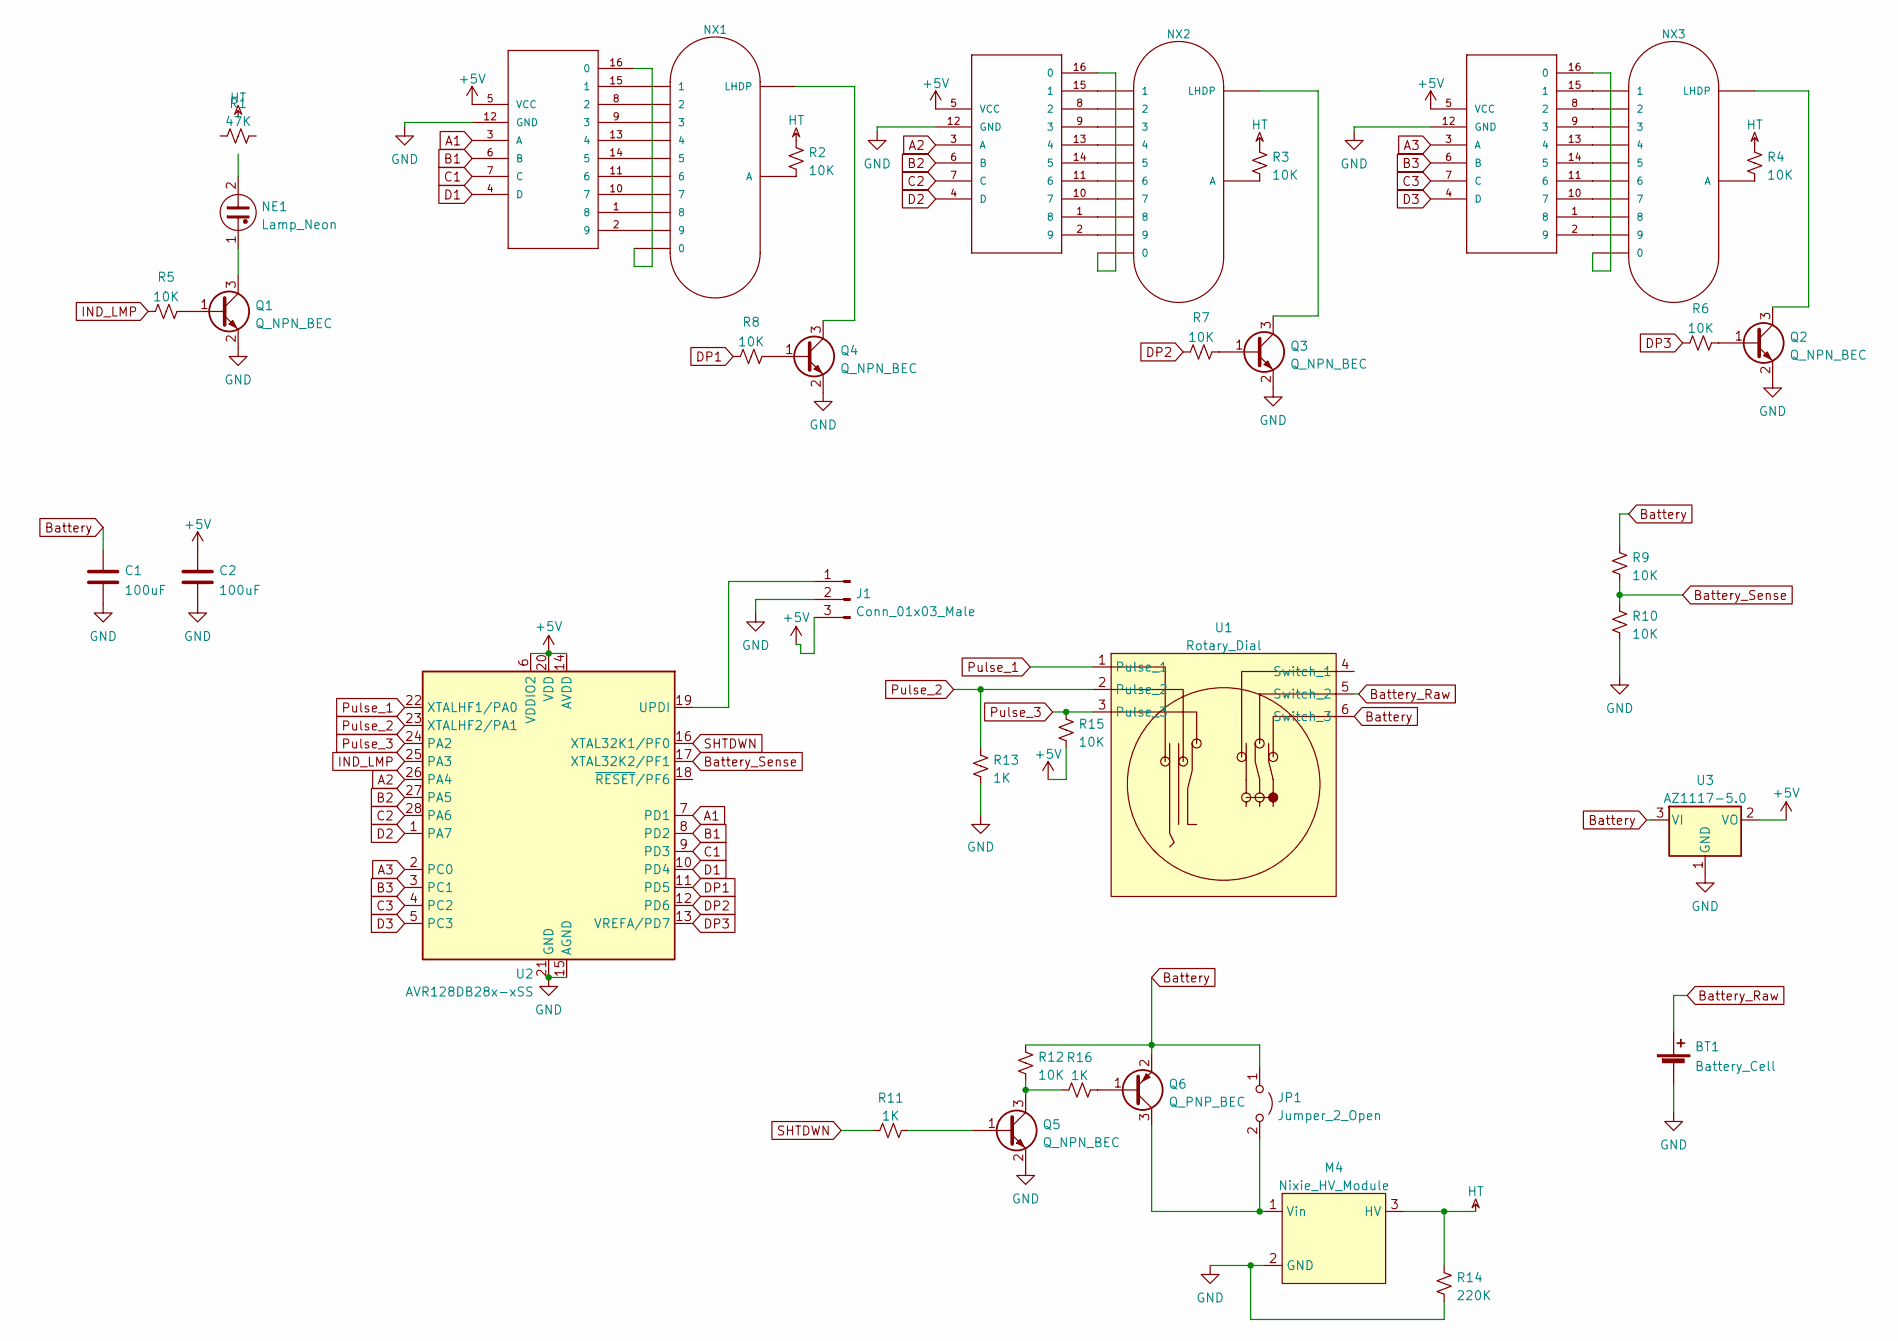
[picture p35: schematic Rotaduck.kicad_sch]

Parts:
BT1: Battery_Cell; PinHeader_1x02_P2.54mm_Vertical
C1, C2: 100uF; C_1206_3216Metric_Pad1.33x1.80mm_HandSolder
J1: Conn_01x03_Male; PinHeader_1x03_P2.54mm_Vertical
JP1: Jumper_2_Open; SolderJumper-2_P1.3mm_Open_RoundedPad1.0x1.5mm
M1, M2, M3: 74141DIP16; DIP-16_W7.62mm
M4: Nixie_HV_Module; Nixie_HV_Module_Small
NE1: Lamp_Neon; PinHeader_1x02_P2.54mm_Vertical
NX1, NX2, NX3: IN-12BNOHOLE; nixies-us-IN-12-DSUB
Q1, Q2, Q3, Q4, Q5: Q_NPN_BEC; SOT-23
Q6: Q_PNP_BEC; SOT-23
R1: 47K; R_1206_3216Metric_Pad1.30x1.75mm_HandSolder
R2, R3, R4: 10K; R_1206_3216Metric_Pad1.30x1.75mm_HandSolder
R5, R6, R7, R8, R9, R10, R12, R15: 10K; R_0805_2012Metric_Pad1.20x1.40mm_HandSolder
R11, R13, R16: 1K; R_0805_2012Metric_Pad1.20x1.40mm_HandSolder
R14: 220K; R_1206_3216Metric_Pad1.30x1.75mm_HandSolder
U1: Rotary_Dial; PinHeader_1x06_P2.54mm_Vertical
U2: AVR128DB28x-xSS; SSOP-28_5.3x10.2mm_P0.65mm
U3: AZ1117-5.0; SOT-223-3_TabPin2

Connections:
+5V: C2.1, J1.3, M1.5 (VCC), M2.5 (VCC), M3.5 (VCC), R15.2, U2.6 (VDDIO2), U2.14 (AVDD), U2.18 (~RESET/PF6), U2.20 (VDD), U3.2 (VO)
A1: M1.3 (A), U2.7 (PD1)
A2: M2.3 (A), U2.26 (PA4)
A3: M3.3 (A), U2.2 (PC0)
B1: M1.6 (B), U2.8 (PD2)
B2: M2.6 (B), U2.27 (PA5)
B3: M3.6 (B), U2.3 (PC1)
Battery: C1.1, JP1.1 (A), Q6.2 (E), R9.2, R12.1, U1.6 (Switch_3), U3.3 (VI)
Battery_Raw: BT1.1 (+), U1.5 (Switch_2)
Battery_Sense: R9.1, R10.2, U2.17 (XTAL32K2/PF1)
C1: M1.7 (C), U2.9 (PD3)
C2: M2.7 (C), U2.28 (PA6)
C3: M3.7 (C), U2.4 (PC2)
D1: M1.4 (D), U2.10 (PD4)
D2: M2.4 (D), U2.1 (PA7)
D3: M3.4 (D), U2.5 (PC3)
DP1: R8.2, U2.11 (PD5)
DP2: R7.2, U2.12 (PD6)
DP3: R6.2, U2.13 (VREFA/PD7)
GND: BT1.2 (-), C1.2, C2.2, J1.2, M1.12 (GND), M2.12 (GND), M3.12 (GND), M4.2 (GND), Q1.2 (E), Q2.2 (E), Q3.2 (E), Q4.2 (E), Q5.2 (E), R10.1, R13.2, R14.2, U2.15 (AGND), U2.21 (GND), U3.1 (GND)
HT: M4.3 (HV), R1.2, R2.2, R3.2, R4.2, R14.1
IND_LMP: R5.2, U2.25 (PA3)
unnamed: J1.1, U2.19 (UPDI)
unnamed: JP1.2 (B), M4.1 (Vin), Q6.3 (C)
unnamed: M1.1 (8), NX1.8
unnamed: M1.2 (9), NX1.9
unnamed: M1.8 (2), NX1.2
unnamed: M1.9 (3), NX1.3
unnamed: M1.10 (7), NX1.7
unnamed: M1.11 (6), NX1.6
unnamed: M1.13 (4), NX1.4
unnamed: M1.14 (5), NX1.5
unnamed: M1.15 (1), NX1.1
unnamed: M1.16 (0), NX1.0
unnamed: M2.1 (8), NX2.8
unnamed: M2.2 (9), NX2.9
unnamed: M2.8 (2), NX2.2
unnamed: M2.9 (3), NX2.3
unnamed: M2.10 (7), NX2.7
unnamed: M2.11 (6), NX2.6
unnamed: M2.13 (4), NX2.4
unnamed: M2.14 (5), NX2.5
unnamed: M2.15 (1), NX2.1
unnamed: M2.16 (0), NX2.0
unnamed: M3.1 (8), NX3.8
unnamed: M3.2 (9), NX3.9
unnamed: M3.8 (2), NX3.2
unnamed: M3.9 (3), NX3.3
unnamed: M3.10 (7), NX3.7
unnamed: M3.11 (6), NX3.6
unnamed: M3.13 (4), NX3.4
unnamed: M3.14 (5), NX3.5
unnamed: M3.15 (1), NX3.1
unnamed: M3.16 (0), NX3.0
unnamed: NE1.1, Q1.3 (C)
unnamed: NE1.2, R1.1
unnamed: NX1.A, R2.1
unnamed: NX1.LHDP, Q4.3 (C)
unnamed: NX2.A, R3.1
unnamed: NX2.LHDP, Q3.3 (C)
unnamed: NX3.A, R4.1
unnamed: NX3.LHDP, Q2.3 (C)
unnamed: Q1.1 (B), R5.1
unnamed: Q2.1 (B), R6.1
unnamed: Q3.1 (B), R7.1
unnamed: Q4.1 (B), R8.1
unnamed: Q5.3 (C), R12.2, R16.1
unnamed: Q5.1 (B), R11.1
unnamed: Q6.1 (B), R16.2
Pulse_1: U1.1 (Pulse_1), U2.22 (XTALHF1/PA0)
Pulse_2: R13.1, U1.2 (Pulse_2), U2.23 (XTALHF2/PA1)
Pulse_3: R15.1, U1.3 (Pulse_3), U2.24 (PA2)
SHTDWN: R11.2, U2.16 (XTAL32K1/PF0)

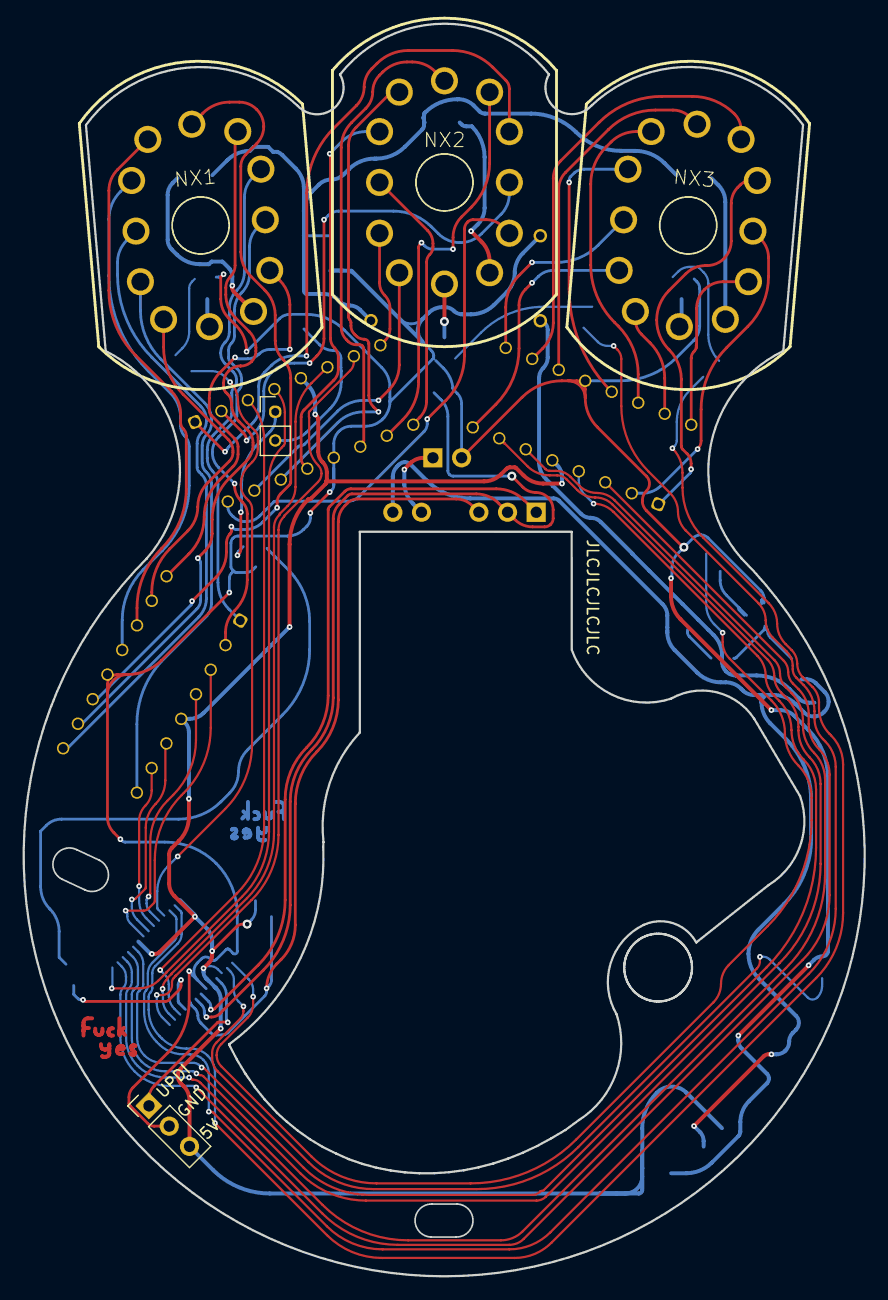
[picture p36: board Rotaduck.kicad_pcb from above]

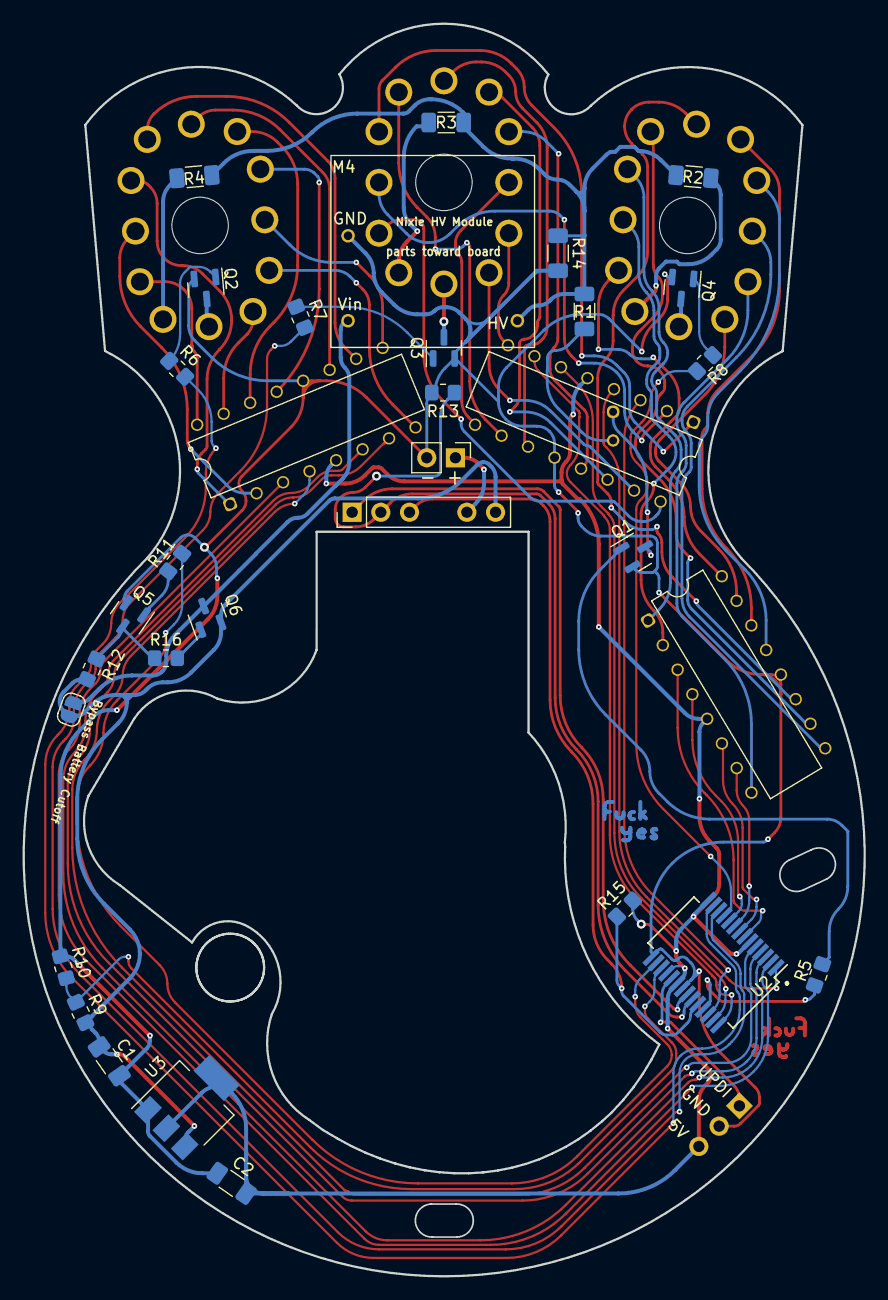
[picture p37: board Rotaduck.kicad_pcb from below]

Board: 2 copper layers, 74.5 x 110.9 mm, 38 parts (33 on the bottom side), 73 nets.

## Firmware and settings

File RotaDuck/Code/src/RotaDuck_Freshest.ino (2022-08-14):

/*


here's the special function menu map

note - I'm calling moving the dial just a little to turn the display on a "click"

when inside a special function, dial anything to exit (preferably 0 because it's only reading intermittently when in menus, so it's most likely to register)

0 -- enter/exit menu or funtion   shows 111 when you're in the menu)
1 -- stopwatch                    click to start, click again to see last time.
2 -- show battery voltage         briefly turns off the display to get a more accurate reading (not under load)
3 -- new day                      this stores the total since the last time you started a new day. maximum 63 days
4 -- does nothing
5 -- enter a count by digits      enter 3 digits (hundreds - tens - ones) to add to your daily total
6 -- show history                 click through each day with first the day number (on the left) then the total for that day
7 -- toggle day/total display     either shows the count for that day or the running total of all days (default is total)
8 -- golf mode?                   maybe I'll add a mode where it will keep score for golf or whatever
9 -- clear everything             dial 9 again to confirm. dial anything else to go back

999999 -- emergency clear         dial 9 six times to emergency clear everything in case something gets messed up same as dialing 10 9 9


*/

#include <EEPROM.h>

#define ENTADDR 0x10 // 1 byte, 32 slots, ends at 0x2F
#define ENTNUMADDR 0x04

#define TOTADDR 0x30 // 2 bytes, 32 slots, ends at 0x6F
#define TOTLEN 0x03

#define COUNTADDRH 0x01 // keep current total here High Byte
#define COUNTADDRL 0x02 // keep current total here Low Byte

#define BACKUPCOUNTH 0xF1
#define BACKUPCOUNTL 0xF2

#define TOTALCOUNTH 0x0B
#define TOTALCOUNTL 0x0C

#define SPECIALSELECTION 0x09

#define SPECIALMENUFLAG 0xE0

#define STOPWATCHFLAG 0xE1
#define VOLTAGEFLAG 0xE2
#define NEWDAYFLAG 0xE3
#define ENTERTOTALFLAG 0xE5
#define SHOWHISTORYFLAG 0xE6
#define DAYTOTALDISPLAYFLAG 0xE7
#define GOLFMODEFLAG 0xE8 // I might come up with a low power mode someday
#define CLEAREVERYTHINGFLAG 0xE9

#define GOLFSUBTRACTFLAG 0xED
#define GOLFHOLE 0xEA
#define GOLFPLAYER 0xEB
#define GOLFNUMPLAYERS 0xEC
#define TEMPPLAYER 0xEE
#define TEMPHOLE 0xEF

#define PLAYER1SCORE 0xD1
#define PLAYER2SCORE 0xD2
#define PLAYER3SCORE 0xD3
#define PLAYER4SCORE 0xD4

#define GOLFTOTALFLAG 0xD0

#define TIMEDIGITSTART 0xC0 // move this to not wear out the EEPROM

#define SUBFLAG 0x05
#define CLEARFLAG 0x06

#define dp0 PIN_PD5
#define dp1 PIN_PD6
#define dp2 PIN_PD7
#define ind PIN_PA3

#define pulse1 PIN_PA0
#define pulse2 PIN_PA1
#define pulse3 PIN_PA2

#define MEMLEN 64

int8_t entries[33] = {0x00, 0x00, 0x00, 0x00, 0x00, 0x00, 0x00, 0x00, 0x00, 0x00, 0x00, 0x00, 0x00, 0x00, 0x00, 0x00, 0x00, 0x00, 0x00, 0x00, 0x00, 0x00, 0x00, 0x00, 0x00, 0x00, 0x00, 0x00, 0x00, 0x00, 0x00, 0x00};

uint8_t totals[2][MEMLEN + 1] = {{0x00, 0x00, 0x00, 0x00, 0x00, 0x00, 0x00, 0x00, 0x00, 0x00, 0x00, 0x00, 0x00, 0x00, 0x00, 0x00, 0x00, 0x00, 0x00, 0x00, 0x00, 0x00, 0x00, 0x00, 0x00, 0x00, 0x00, 0x00, 0x00, 0x00, 0x00, 0x00, 0x00, 0x00, 0x00, 0x00, 0x00, 0x00, 0x00, 0x00, 0x00, 0x00, 0x00, 0x00, 0x00, 0x00, 0x00, 0x00, 0x00, 0x00, 0x00, 0x00, 0x00, 0x00, 0x00, 0x00, 0x00, 0x00, 0x00, 0x00, 0x00, 0x00, 0x00, 0x00, 0x00}, {0x00, 0x00, 0x00, 0x00, 0x00, 0x00, 0x00, 0x00, 0x00, 0x00, 0x00, 0x00, 0x00, 0x00, 0x00, 0x00, 0x00, 0x00, 0x00, 0x00, 0x00, 0x00, 0x00, 0x00, 0x00, 0x00, 0x00, 0x00, 0x00, 0x00, 0x00, 0x00, 0x00, 0x00, 0x00, 0x00, 0x00, 0x00, 0x00, 0x00, 0x00, 0x00, 0x00, 0x00, 0x00, 0x00, 0x00, 0x00, 0x00, 0x00, 0x00, 0x00, 0x00, 0x00, 0x00, 0x00, 0x00, 0x00, 0x00, 0x00, 0x00, 0x00, 0x00, 0x00, 0x00}};
// totals[0][] is High Byte    totals [1][] is Low Byte

uint8_t playerScore[4][20] = {{0x00, 0x00, 0x00, 0x00, 0x00, 0x00, 0x00, 0x00, 0x00, 0x00, 0x00, 0x00, 0x00, 0x00, 0x00, 0x00, 0x00, 0x00, 0x00, 0x00}, {0x00, 0x00, 0x00, 0x00, 0x00, 0x00, 0x00, 0x00, 0x00, 0x00, 0x00, 0x00, 0x00, 0x00, 0x00, 0x00, 0x00, 0x00, 0x00, 0x00}, {0x00, 0x00, 0x00, 0x00, 0x00, 0x00, 0x00, 0x00, 0x00, 0x00, 0x00, 0x00, 0x00, 0x00, 0x00, 0x00, 0x00, 0x00, 0x00, 0x00}, {0x00, 0x00, 0x00, 0x00, 0x00, 0x00, 0x00, 0x00, 0x00, 0x00, 0x00, 0x00, 0x00, 0x00, 0x00, 0x00, 0x00, 0x00, 0x00, 0x00}};

unsigned long previousMillis = 0;
const long interval = 150;
long intervalStopwatch = 10;
int dpCount = 0;

int mil = 1;

int duckCount = 0;

uint8_t duckCountH = 0;
uint8_t duckCountL = 0;

uint8_t dayTotal = 0;

uint16_t totalCount = 0;

uint8_t totalCountH = 0;
uint8_t totalCountL = 0;

uint8_t subtractFlag = 0;
uint8_t clearFlag = 0;

int pulseCount = 0;

uint8_t totlen = 0;
uint8_t entlen = 0;

// make sure to set BOD higher and read eeprom a few times at startup

const int truthBCD[10][4] = {

    {0, 0, 0, 0},
    {0, 0, 0, 1}, //
    {0, 0, 1, 0},
    {0, 0, 1, 1},
    {0, 1, 0, 0},
    {0, 1, 0, 1},
    {0, 1, 1, 0}, //
    {0, 1, 1, 1},
    {1, 0, 0, 0},
    {1, 0, 0, 1}

};

int enteredTotal1 = EEPROM.read(0xCA);
int enteredTotal2 = EEPROM.read(0xCB);
int enteredTotal3 = EEPROM.read(0xCC);

int golfHole = EEPROM.read(GOLFHOLE);
int golfPlayer = EEPROM.read(GOLFPLAYER);
uint8_t golfMode = EEPROM.read(GOLFMODEFLAG);
uint8_t golfNumPlayers = EEPROM.read(GOLFNUMPLAYERS);

int dispDig0 = 0;
int dispDig1 = 0;
int dispDig2 = 0;

uint8_t blanking = 1;
uint8_t leftJustified = 0;
uint8_t centered = 0;

void setup()
{
  splitBCD(-1);      //-1 shows nothing
  EEPROM.read(0x0D); // check for first startup (but this read gets thrown away because EEPROM can be weird)

  pinMode(PIN_PF0, OUTPUT); // this enables power to the HV supply
  digitalWriteFast(PIN_PF0, HIGH);

  pinMode(PIN_PD5, OUTPUT);
  pinMode(PIN_PD6, OUTPUT);
  pinMode(PIN_PD7, OUTPUT);
  digitalWriteFast(PIN_PD5, LOW);
  digitalWriteFast(PIN_PD6, LOW);
  digitalWriteFast(PIN_PD7, LOW);

  pinMode(PIN_PA4, OUTPUT);
  pinMode(PIN_PA5, OUTPUT);
  pinMode(PIN_PA6, OUTPUT);
  pinMode(PIN_PA7, OUTPUT);

  pinMode(pulse1, INPUT_PULLUP);
  pinMode(pulse2, INPUT);
  pinMode(pulse3, INPUT);
  pinMode(PIN_PA2, INPUT);

  pinMode(PIN_PA3, OUTPUT);

  pinMode(PIN_PD1, OUTPUT);
  pinMode(PIN_PD2, OUTPUT);
  pinMode(PIN_PD3, OUTPUT);
  pinMode(PIN_PD4, OUTPUT);

  pinMode(PIN_PF1, INPUT);

  pinMode(PIN_PC0, OUTPUT);
  pinMode(PIN_PC1, OUTPUT);
  pinMode(PIN_PC2, OUTPUT);
  pinMode(PIN_PC3, OUTPUT);

  analogReadResolution(10);
  analogSampleDuration(500);

  if (EEPROM.read(0x0D) != 0x69 || EEPROM.read(CLEARFLAG) >= 0x03 || digitalRead(pulse2) == 1) // sets everything up on first startup or emergency clear (6 9's in a row) or super emergengy hardware clear by pulling pulse 2 high
  {

    voltageDisplay(5);

    initEEPROM();
    duckCount = 0;
    EEPROM.update(COUNTADDRH, 0);
    EEPROM.update(COUNTADDRL, 0);
  }
  else
  {

    duckCountH = EEPROM.read(COUNTADDRH);
    duckCountL = EEPROM.read(COUNTADDRL);

    totalCountH = EEPROM.read(TOTALCOUNTH);
    totalCountL = EEPROM.read(TOTALCOUNTL);

    totlen = EEPROM.read(TOTLEN);
    entlen = EEPROM.read(ENTNUMADDR);

    bytes2dc();
  }
  if (EEPROM.read(DAYTOTALDISPLAYFLAG) == 0xDA) // show daily count or total count
  {
    dayTotal = 1;
  }
  else
  {
    dayTotal = 0;
  }

  if (EEPROM.read(SPECIALMENUFLAG) == 0xFF) // if it's 0xFF then we aren't in a special menu
  {
    if (dayTotal == 1)
    {
      splitBCD(duckCount);
    }
    else
    {
      splitBCD(totalCount);
    }
  }

  subtractFlag = EEPROM.read(SUBFLAG);

  if (EEPROM.read(SPECIALMENUFLAG) == 0xAA || EEPROM.read(SPECIALMENUFLAG) == 0x18)
  {
    specialMenu(); // this function takes input from the dial
  }
  if (EEPROM.read(SPECIALMENUFLAG) != 0xFF && EEPROM.read(SPECIALMENUFLAG) != 0x18)
  {
    checkSpecialMenuFlags(); // this one doesn't
  }

  loadHistory();
}

void loop()
{

  if (golfMode != 0x01)
  {
    if (dayTotal == 1)
    {
      splitBCD(duckCount);
    }
    else
    {
      splitBCD(totalCount);
    }
  }
  readDial(0);

  writedc();
}

void checkSpecialMenuFlags(void)
{

  uint8_t smFlagVal = EEPROM.read(SPECIALMENUFLAG);

  switch (smFlagVal)
  {
  case 0xFF:
    return;

  case 0x01:
    if (EEPROM.read(STOPWATCHFLAG) == 0xFF)
    {
      EEPROM.update(STOPWATCHFLAG, 0x01);
    }

    stopwatch();
    while (1)
      ;

  case 0x02:
    while (digitalRead(pulse1) == 0)
    {
      voltageDisplay(8);

      for (int i = 0; i < 40; i++)
      { // this works as a sort of interrupt to get out of voltage display

        if (digitalRead(pulse1) == 1)
        {
          EEPROM.update(SPECIALMENUFLAG, 0xFF);
          while (1)
            ;
        }
        else
        {
          delay(20);
        }
      }
    }
    return;

  case 0x03:
    EEPROM.update(SPECIALMENUFLAG, 0xFF);
    newDay();
    return;

  case 0x05:

    enterStartingTotal();

    while (1)
      ;

  case 0x06:
    if (golfMode == 1)
    {
      EEPROM.update(SHOWHISTORYFLAG, 0xEE);
      showGolfHistory();
      return;
    }

    if (EEPROM.read(SHOWHISTORYFLAG) == 0xFF)
    {
      EEPROM.update(SHOWHISTORYFLAG, EEPROM.read(TOTLEN));
      EEPROM.update(SPECIALMENUFLAG, 0x06);
      EEPROM.update(SPECIALSELECTION, 0x06);
    }

    showHistory();

    return;

  case 0x07:
    EEPROM.update(SPECIALMENUFLAG, 0xFF);
    if (EEPROM.read(DAYTOTALDISPLAYFLAG) != 0xDA)
    {
      EEPROM.update(DAYTOTALDISPLAYFLAG, 0xDA);
      dayTotal = 1;
    }
    else
    {
      EEPROM.update(DAYTOTALDISPLAYFLAG, 0xFF);
      dayTotal = 0;
    }
    return;

  case 0x08:

    if (EEPROM.read(GOLFMODEFLAG) == 0x01)
    {
      golfMode = 0;
      EEPROM.update(SPECIALMENUFLAG, 0xFF);
      EEPROM.update(GOLFMODEFLAG, 0xFF);
      EEPROM.update(DAYTOTALDISPLAYFLAG, 0xFF);
      dayTotal = 0;
      initEEPROM();
    }
    else
    {
      EEPROM.update(DAYTOTALDISPLAYFLAG, 0xDA); // golf mode defaults to showing days (holes)
      dayTotal = 1;
      EEPROM.update(SPECIALMENUFLAG, 0x18);
      duckCount = 0;
      totalCount = 0;
      writedc();
      clearAllEntries();
    }

    specialMenu();
    return;

  case 0x09:

    EEPROM.update(CLEAREVERYTHINGFLAG, 0x99);
    EEPROM.update(SPECIALMENUFLAG, 0xAA);
    subtractFlag = 2;
    EEPROM.update(SUBFLAG, 0x02);
    splitBCD(totalCount);
    specialMenu();
  }

  if (EEPROM.read(SHOWHISTORYFLAG) > 0x00 && EEPROM.read(SHOWHISTORYFLAG) < 0x40)
  {

    showHistory();
  }
}

void specialMenu(void)
{

  uint8_t specialSelection = 0;
  uint8_t smFlagVal = EEPROM.read(SPECIALMENUFLAG);
  golfMode = 0;

  if (EEPROM.read(CLEAREVERYTHINGFLAG) == 0x99)
  {

    while (1)
    {

      specialSelection = abs(readDial(9));

      if (specialSelection > 0)
      {
        break;
      }
    }

    if (specialSelection == 9) // clear confirmed
    {
      subtractFlag = 0;
      EEPROM.update(SUBFLAG, subtractFlag);
      EEPROM.update(SPECIALMENUFLAG, 0xFF);
      EEPROM.update(CLEAREVERYTHINGFLAG, 0xFF);

      initEEPROM();
      return;
    }
    else // didn't confirm clear
    {

      subtractFlag = 0;
      EEPROM.update(SUBFLAG, subtractFlag);
      EEPROM.update(SPECIALMENUFLAG, 0xFF);
      EEPROM.update(CLEAREVERYTHINGFLAG, 0xFF);
      return;
    }
  }

  if (EEPROM.read(SUBFLAG) == 1 || EEPROM.read(SUBFLAG) == 2)
  {
    subtractFlag = 0;
    EEPROM.update(SUBFLAG, subtractFlag);
    return;
  }

  if (smFlagVal == 0xAA)
  {
    while (1)
    {
      splitBCD(111);
      specialSelection = readDial(1);
      if (specialSelection > 0)
      {
        break;
      }
    }

    if (specialSelection == 10)
    {
      EEPROM.update(SPECIALMENUFLAG, 0xFF);
      while (1)
        ;
    }

    EEPROM.update(SPECIALMENUFLAG, specialSelection);

    while (1)
      ;
  }
  else if (smFlagVal == 0x18)
  {
    askHowManyPlayers();
  }
  else
  {
    checkSpecialMenuFlags();
  }
}

void askHowManyPlayers(void)
{
  int animationCount = 0;
  int golfSelection = 0;
  unsigned long previousMillisg = 0;

  while (animationCount < 6 && digitalRead(pulse1) == 0)
  {

    unsigned long currentMillisg = millis();

    if (currentMillisg - previousMillisg >= 120)
    {

      previousMillisg = currentMillisg;
      animationCount++;
    }
    switch (animationCount)
    {

    case 0:
      leftJustified = 1;
      splitBCD(7);

      digitalWriteFast(dp2, LOW);
      digitalWriteFast(dp1, LOW);
      digitalWriteFast(dp0, HIGH);
      digitalWriteFast(ind, LOW);
      leftJustified = 0;
      break;
    case 1:
      leftJustified = 1;
      splitBCD(7);

      digitalWriteFast(dp2, LOW);
      digitalWriteFast(dp1, LOW);
      digitalWriteFast(dp0, HIGH);
      digitalWriteFast(ind, LOW);
      leftJustified = 0;
      break;
    case 2:
      leftJustified = 1;
      splitBCD(1);
      digitalWriteFast(dp2, LOW);
      digitalWriteFast(dp1, HIGH);
      digitalWriteFast(dp0, LOW);
      digitalWriteFast(ind, LOW);
      leftJustified = 0;
      break;
    case 3:
      leftJustified = 1;
      splitBCD(1);
      digitalWriteFast(dp2, HIGH);
      digitalWriteFast(dp1, LOW);
      digitalWriteFast(dp0, LOW);
      digitalWriteFast(ind, LOW);
      leftJustified = 0;
      break;
    case 4:
      leftJustified = 1;
      splitBCD(1);
      digitalWriteFast(dp2, LOW);
      digitalWriteFast(dp1, LOW);
      digitalWriteFast(dp0, LOW);
      digitalWriteFast(ind, LOW);
      leftJustified = 0;
      break;
    case 5:
      leftJustified = 1;
      splitBCD(1);
      digitalWriteFast(dp2, LOW);
      digitalWriteFast(dp1, LOW);
      digitalWriteFast(dp0, LOW);
      digitalWriteFast(ind, LOW);
      leftJustified = 0;
      break;
    case 6:
      leftJustified = 1;
      splitBCD(1);
      digitalWriteFast(dp2, LOW);
      digitalWriteFast(dp1, LOW);
      digitalWriteFast(dp0, LOW);
      digitalWriteFast(ind, LOW);
      leftJustified = 0;
      break;
    }
  }
  while (1)
  {
    splitBCD(1);

    golfPlayerDP(0, 1);

    golfSelection = readDial(18);
    if (golfSelection > 0)
    {
      break;
    }
    else
    {
      golfPlayerDP(0, 1);
    }
  }
  if (golfSelection > 4)
  {

    while (1)
      ;
  }

  if (golfSelection == 10)
  {
    EEPROM.update(SPECIALMENUFLAG, 0xFF);
    while (1)
      ;
  }

  golfNumPlayers = golfSelection;
  EEPROM.update(GOLFNUMPLAYERS, golfNumPlayers);
  EEPROM.update(SPECIALMENUFLAG, 0xFF);
  EEPROM.update(GOLFPLAYER, 0x00);
  EEPROM.update(GOLFHOLE, 0x00);

  if (EEPROM.read(GOLFMODEFLAG) != 0x01)
  {
    golfMode = 1;
    EEPROM.update(GOLFMODEFLAG, 0x01);
  }

  clearAllEntries();
  while (1)
    ;
}

void golfPlayerDP(int playerNumber, int select)
{

  if (select == 1)
  {
    if (millis() % 180 > 100)
    {
      
      digitalWriteFast(dp2, LOW);
      digitalWriteFast(dp1, LOW);
      digitalWriteFast(dp0, LOW);
      digitalWriteFast(ind, LOW);
      
    }
    else
    {
      switch (playerNumber)
      {
      case -1:
        digitalWriteFast(dp2, LOW);
        digitalWriteFast(dp1, LOW);
        digitalWriteFast(dp0, HIGH);
        digitalWriteFast(ind, LOW);

      case 0:
        digitalWriteFast(dp2, LOW);
        digitalWriteFast(dp1, LOW);
        digitalWriteFast(dp0, HIGH);
        digitalWriteFast(ind, LOW);

        break;
      case 1:
        digitalWriteFast(dp2, LOW);
        digitalWriteFast(dp1, HIGH);
        digitalWriteFast(dp0, HIGH);
        digitalWriteFast(ind, LOW);

        break;
      case 2:
        digitalWriteFast(dp2, HIGH);
        digitalWriteFast(dp1, HIGH);
        digitalWriteFast(dp0, HIGH);
        digitalWriteFast(ind, LOW);

        break;
      case 3:

        digitalWriteFast(dp2, HIGH);
        digitalWriteFast(dp1, HIGH);
        digitalWriteFast(dp0, HIGH);
        digitalWriteFast(ind, HIGH);

        break;
      }
    }
    //} else {
    // mil = 1;
  }
  else
  {
    switch (playerNumber)
    {

    case 0:
      digitalWriteFast(dp2, LOW);
      digitalWriteFast(dp1, LOW);
      digitalWriteFast(dp0, HIGH);
      digitalWriteFast(ind, LOW);

      break;
    case 1:
      digitalWriteFast(dp2, LOW);
      digitalWriteFast(dp1, HIGH);
      digitalWriteFast(dp0, LOW);
      digitalWriteFast(ind, LOW);

      break;
    case 2:
      digitalWriteFast(dp2, HIGH);
      digitalWriteFast(dp1, LOW);
      digitalWriteFast(dp0, LOW);
      digitalWriteFast(ind, LOW);

      break;
    case 3:

      digitalWriteFast(dp2, LOW);
      digitalWriteFast(dp1, LOW);
      digitalWriteFast(dp0, LOW);
      digitalWriteFast(ind, HIGH);

      break;
    }
  }
}

void flashDP(void)
{

  unsigned long currentMillis = millis();
  // subtractFlag = EEPROM.readByte(SUBFLAG );
  if (currentMillis - previousMillis >= interval)
  {

    previousMillis = currentMillis;
    dpCount++;

    if (dpCount > 4)
    {
      dpCount = 0;
    }

    else
    {

      // digitalWriteFast (ind,LOW);
    }
    if (subtractFlag == 2)
    {
      // splitBCD(dpCount);
      switch ((dpCount) % 4)
      {
      case 3:
        digitalWriteFast(dp2, LOW);
        digitalWriteFast(dp1, LOW);
        digitalWriteFast(dp0, LOW);
        digitalWriteFast(ind, HIGH);
        break;

      case 2:
        digitalWriteFast(dp2, HIGH);
        digitalWriteFast(dp1, HIGH);
        digitalWriteFast(dp0, HIGH);
        digitalWriteFast(ind, LOW);
        break;
      case 1:
        digitalWriteFast(dp2, LOW);
        digitalWriteFast(dp1, LOW);
        digitalWriteFast(dp0, LOW);
        digitalWriteFast(ind, HIGH);
        break;
      case 0:
        digitalWriteFast(dp2, HIGH);
        digitalWriteFast(dp1, HIGH);
        digitalWriteFast(dp0, HIGH);
        digitalWriteFast(ind, LOW);
        break;
      }
    }
    else if (subtractFlag == 1)
    {
      // splitBCD(subtractFlag);
      switch ((dpCount) % 4)
      {

      case 3:
        digitalWriteFast(dp2, LOW);
        digitalWriteFast(dp1, LOW);
        digitalWriteFast(dp0, LOW);
        digitalWriteFast(ind, HIGH);
        break;

      case 2:
        digitalWriteFast(dp2, LOW);
        digitalWriteFast(dp1, LOW);
        digitalWriteFast(dp0, HIGH);
        digitalWriteFast(ind, LOW);
        break;
      case 1:
        digitalWriteFast(dp2, LOW);
        digitalWriteFast(dp1, HIGH);
        digitalWriteFast(dp0, LOW);
        digitalWriteFast(ind, LOW);
        break;
      case 0:
        digitalWriteFast(dp2, HIGH);
        digitalWriteFast(dp1, LOW);
        digitalWriteFast(dp0, LOW);
        digitalWriteFast(ind, LOW);
        break;
      }
    }
    else
    {

      switch ((dpCount) % 4)
      {
      case 3:
        digitalWriteFast(dp2, LOW);
        digitalWriteFast(dp1, LOW);
        digitalWriteFast(dp0, LOW);
        digitalWriteFast(ind, HIGH);
        break;

      case 2:
        digitalWriteFast(dp2, HIGH);
        digitalWriteFast(dp1, LOW);
        digitalWriteFast(dp0, LOW);
        digitalWriteFast(ind, LOW);
        break;
      case 1:
        digitalWriteFast(dp2, LOW);
        digitalWriteFast(dp1, HIGH);
        digitalWriteFast(dp0, LOW);
        digitalWriteFast(ind, LOW);
        break;
      case 0:
        digitalWriteFast(dp2, LOW);
        digitalWriteFast(dp1, LOW);
        digitalWriteFast(dp0, HIGH);
        digitalWriteFast(ind, LOW);
        break;
      }
    }
  }
}
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
